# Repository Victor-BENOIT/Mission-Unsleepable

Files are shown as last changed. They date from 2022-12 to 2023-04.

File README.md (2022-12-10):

# Mission-Unsleepable

**Embedded Systems Project - November 2022**

**Collaborator:** Maxence Bigot

**Goal of the project:** 
For our Embedded Systems course, we had to come up with a project using the DEEP Purple Complete Board, a PCB card designed by the ESEO. Maxence and I decided to create an alarm clock that will wake you up everytime. However, smooth waking up is not guaranteed.

**Fonctioning:**
When the alarm rings, you have to push the button on the hatch to stop it. Nevertheless, when your hand will be detected by the sensor the hatch will flip and you will not be able to stop the alarm. If you take away your hand, the hatch will rotate back to its original position and reveal you the button. The only way to stop the alarm is to have a hand on top of the alarm clock, and to push the button underneath the lid through the hole in the back.

**Features:**
- Video alarm
- Custom ringtone and video
- Navigation through menus and options with a joystick

**Components:**
- LCD Screen 3 inches ILI9341
- Servo Motor MG996R
- Ultrasonic Sensor HCSR04
- Button
- Joystick
- Speaker TMQ60500
- Audio Amplificator PAM8403
- mp3 Player HW311
- Nucleo STM32
- BluePill
- Deep Purple Complete Board

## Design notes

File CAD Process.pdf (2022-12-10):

Victor BENOIT

# CAD Process

# Embedded Systems Project

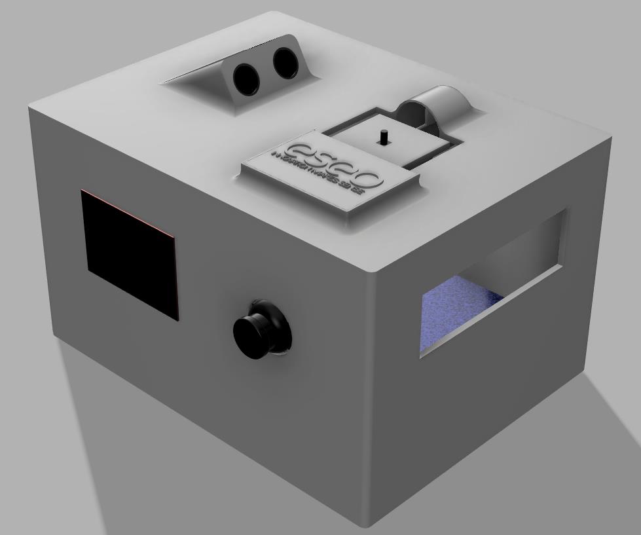
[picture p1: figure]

# MISSION UNSPLEEPABLE

# Steps of design development:

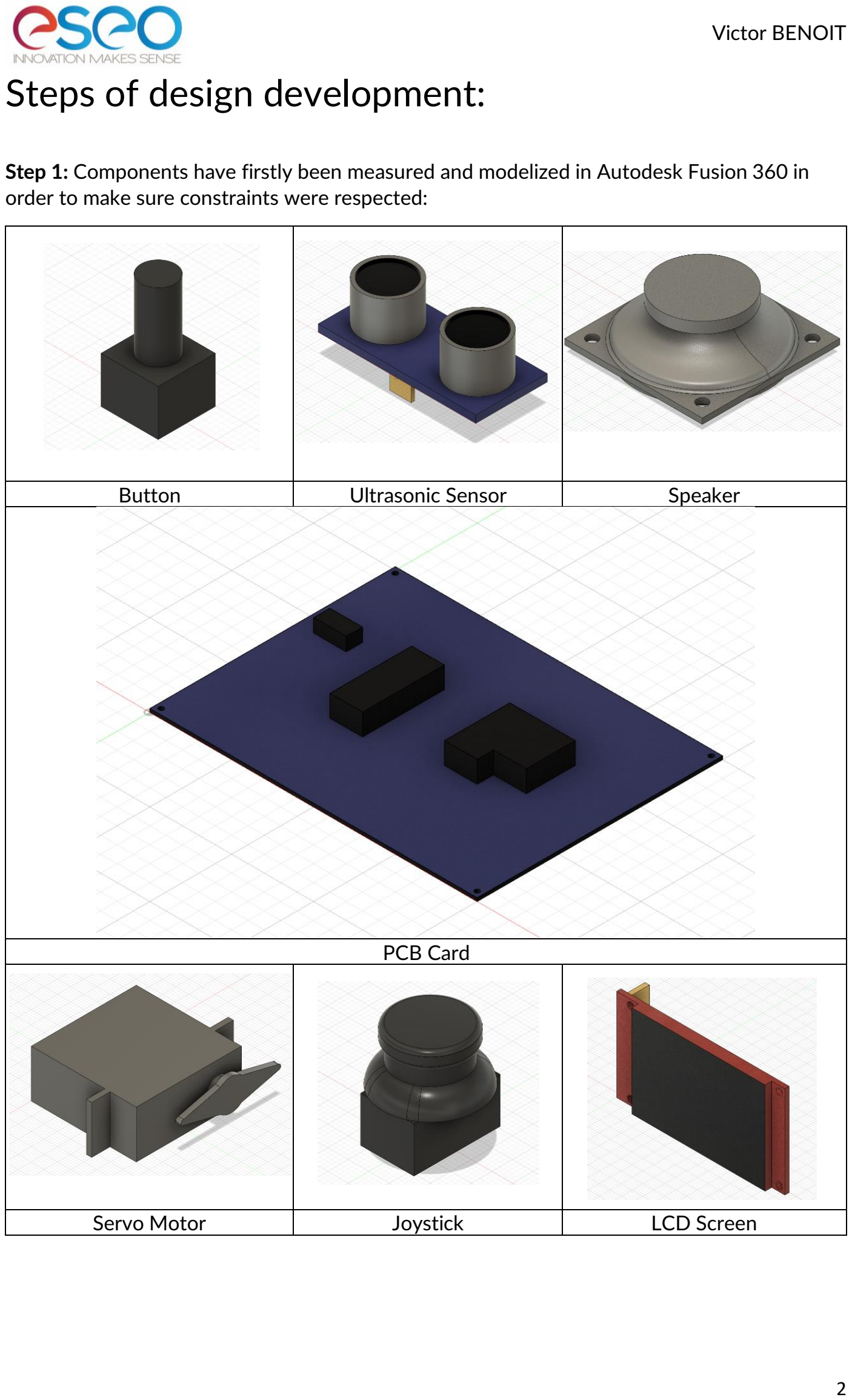
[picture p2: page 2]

Step 1: Components have firstly been measured and modelized in Autodesk Fusion 360 in order to make sure constraints were respected:
Button | Ultrasonic Sensor | Speaker

PCB Card

Servo Motor | Joystick | LCD Screen

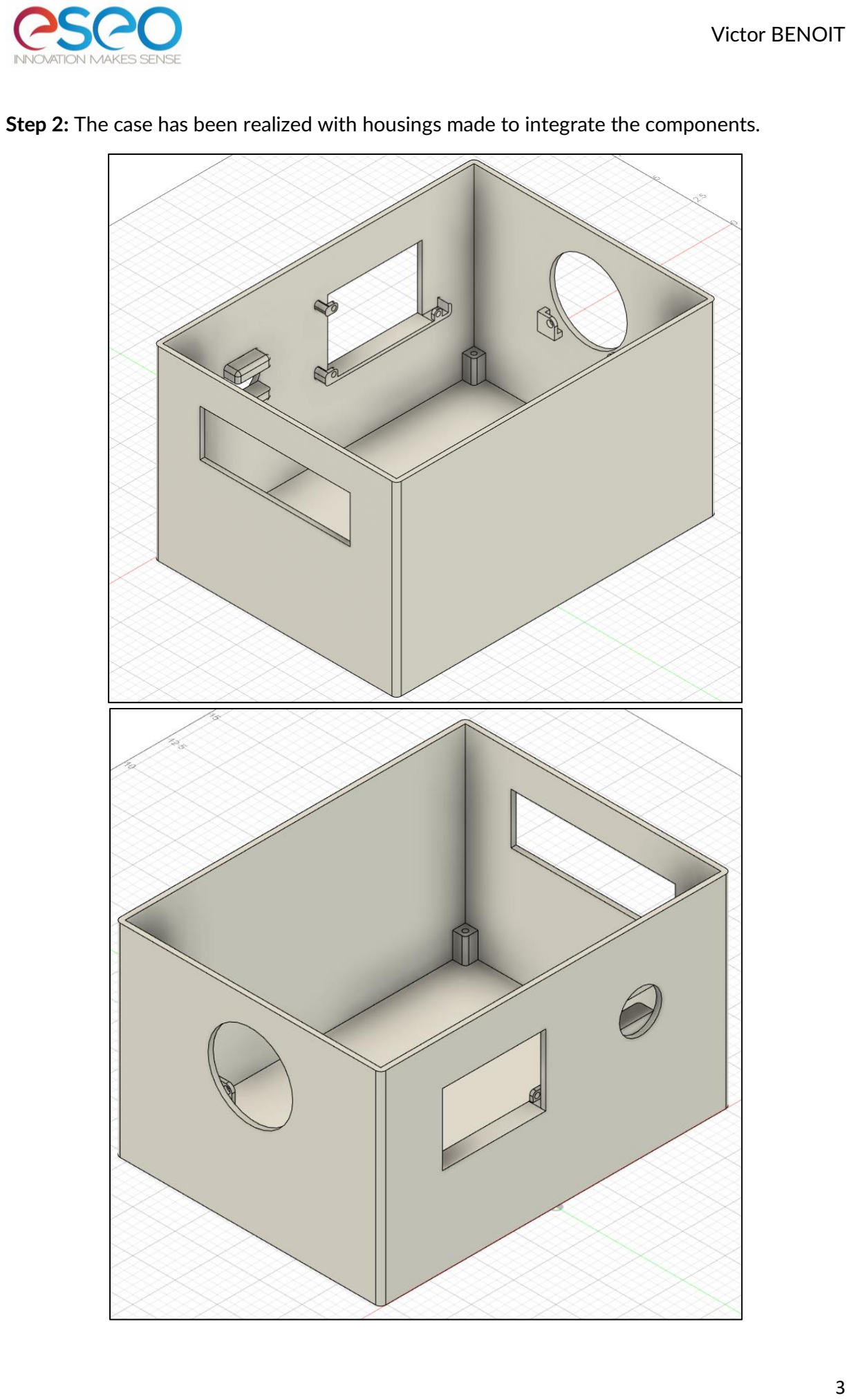
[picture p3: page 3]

Step 2: The case has been realized with housings made to integrate the components.

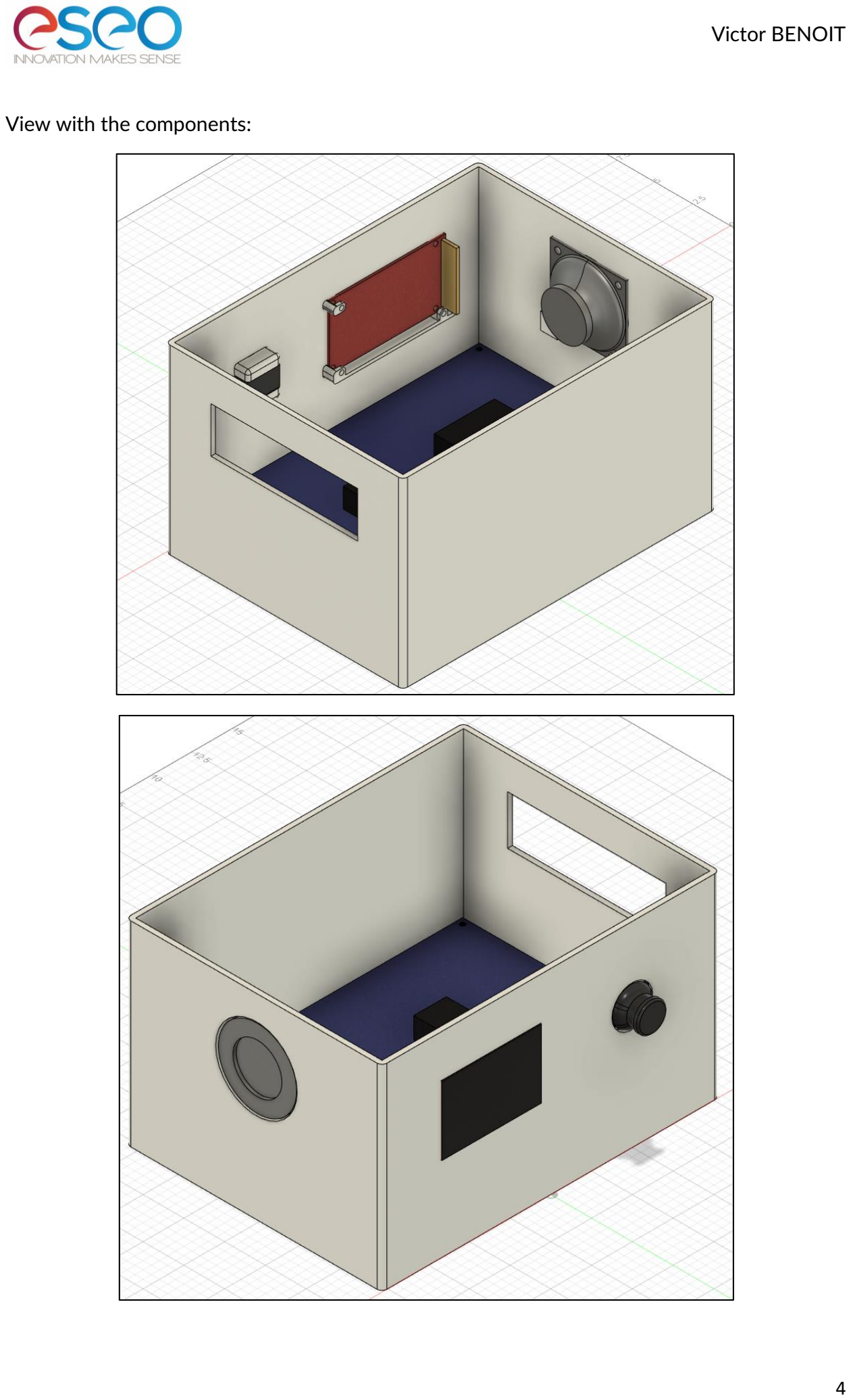
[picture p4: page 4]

View with the components:

Example of a fixation system:

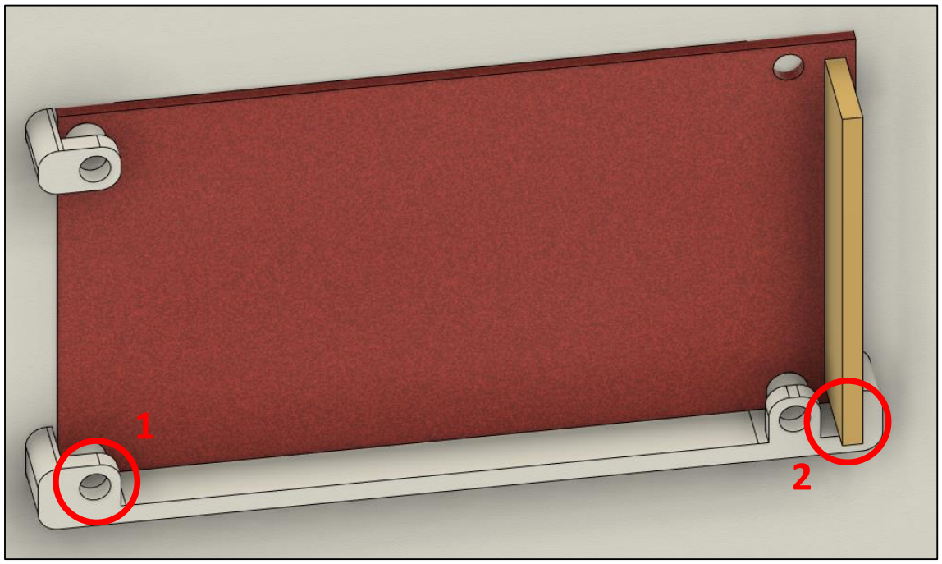
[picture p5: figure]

1) Space of 0.5mm made to slide the LCD Screen in from the top and then push it into the housing. The width of the screen is 0.3mm and the card 0.2mm. Once pushed in, bolts of 0.3mm can be placed to fix the component.
2) Space planned to have access to the pins of the LCD. Ledge designed to maintain the horizontal support of the card.

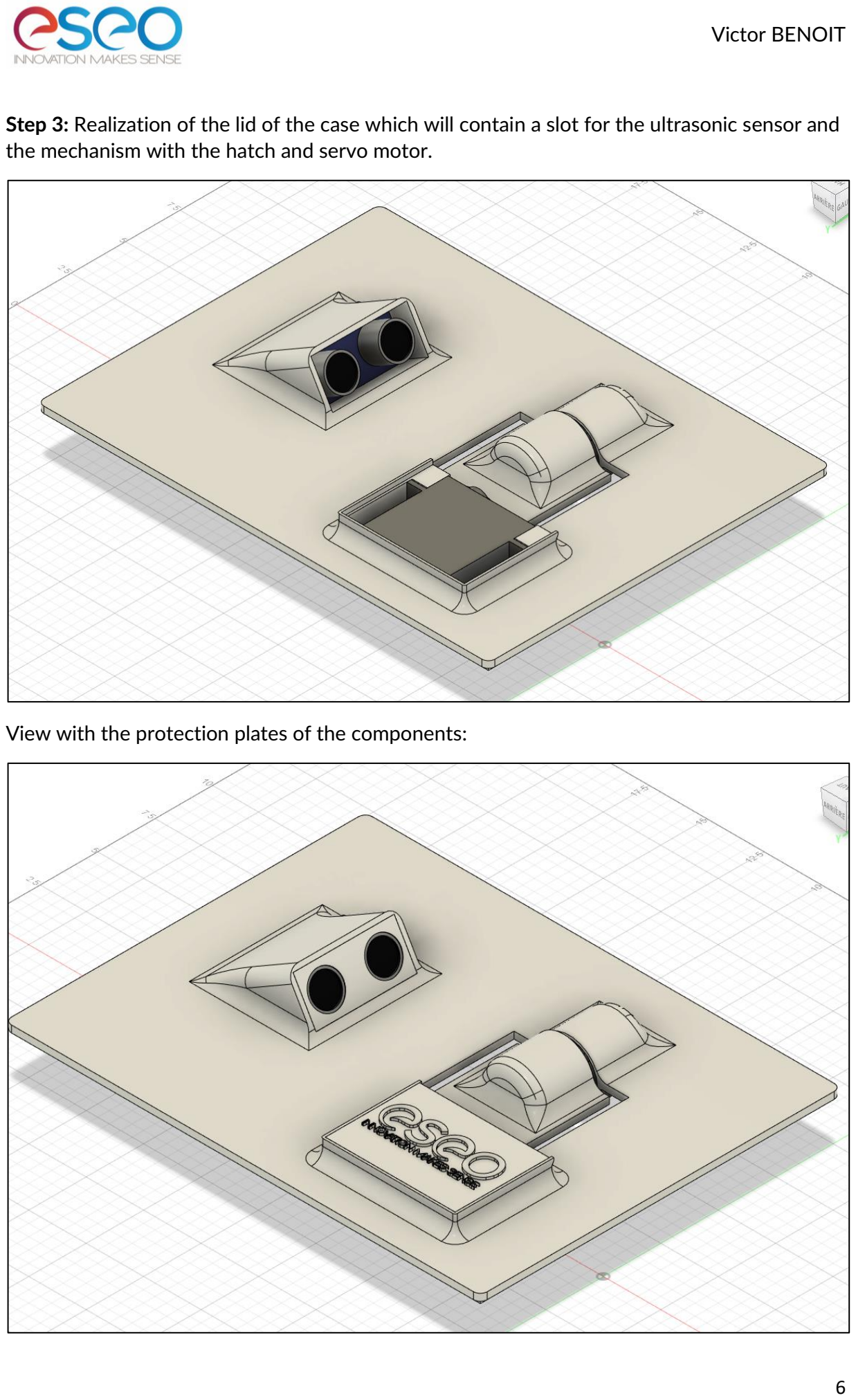
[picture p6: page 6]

Step 3: Realization of the lid of the case which will contain a slot for the ultrasonic sensor and the mechanism with the hatch and servo motor.

View with the protection plates of the components:

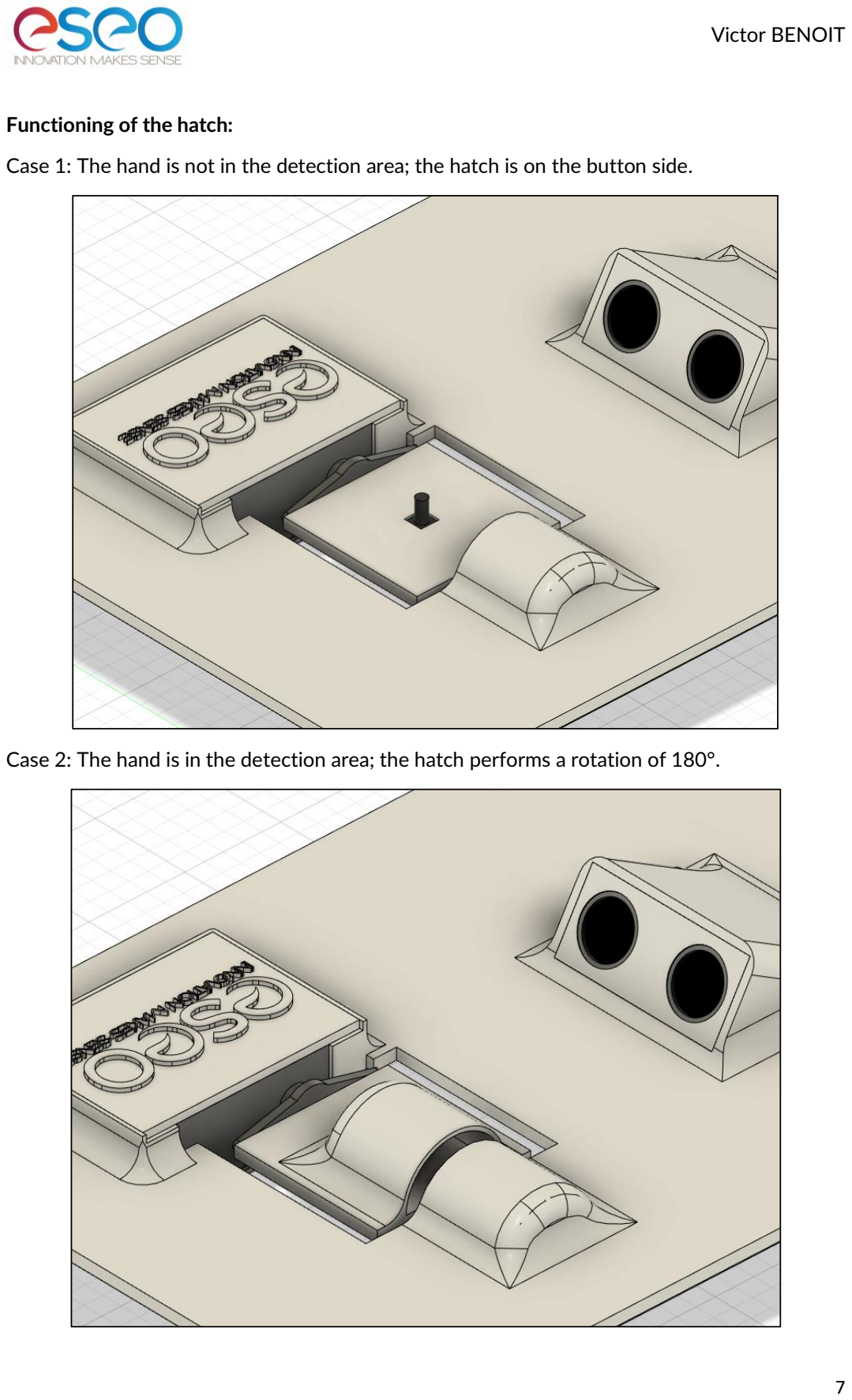
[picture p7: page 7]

Functioning of the hatch:

Case 1: The hand is not in the detection area; the hatch is on the button side.

Case 2: The hand is in the detection area; the hatch performs a rotation of 180°.

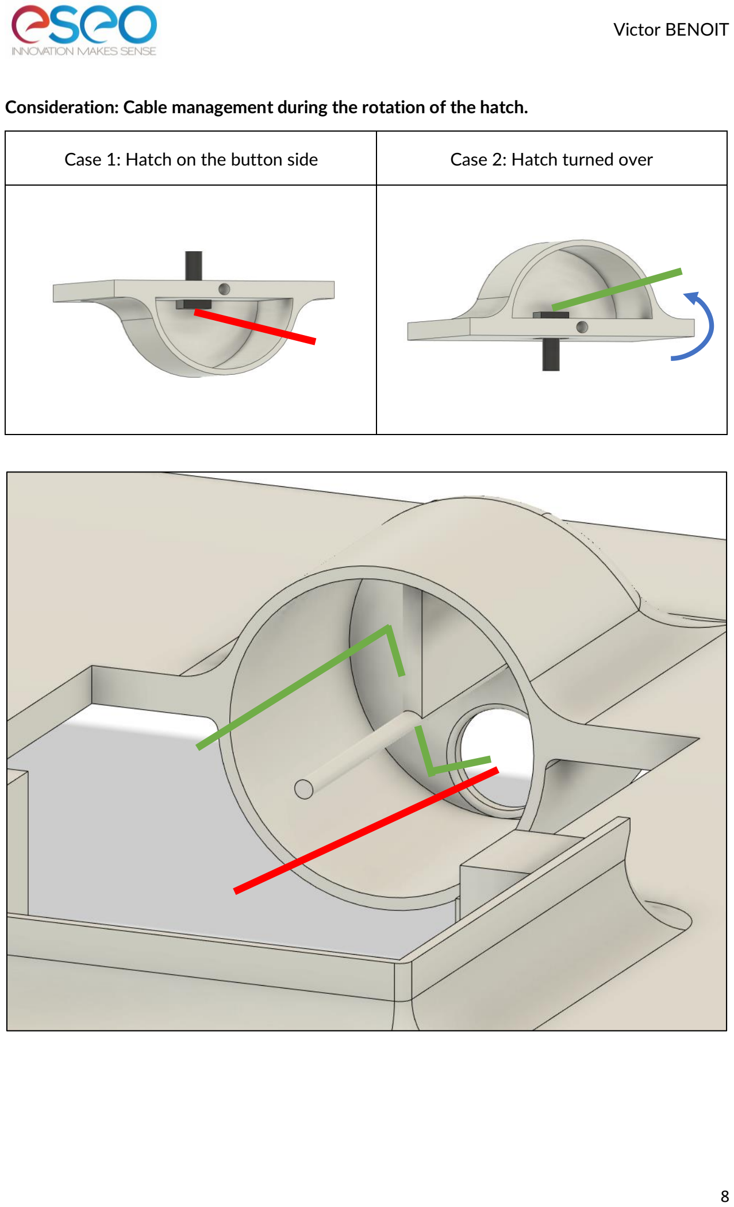
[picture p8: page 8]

Consideration: Cable management during the rotation of the hatch.

Case 1: Hatch on the button side | Case 2: Hatch turned over

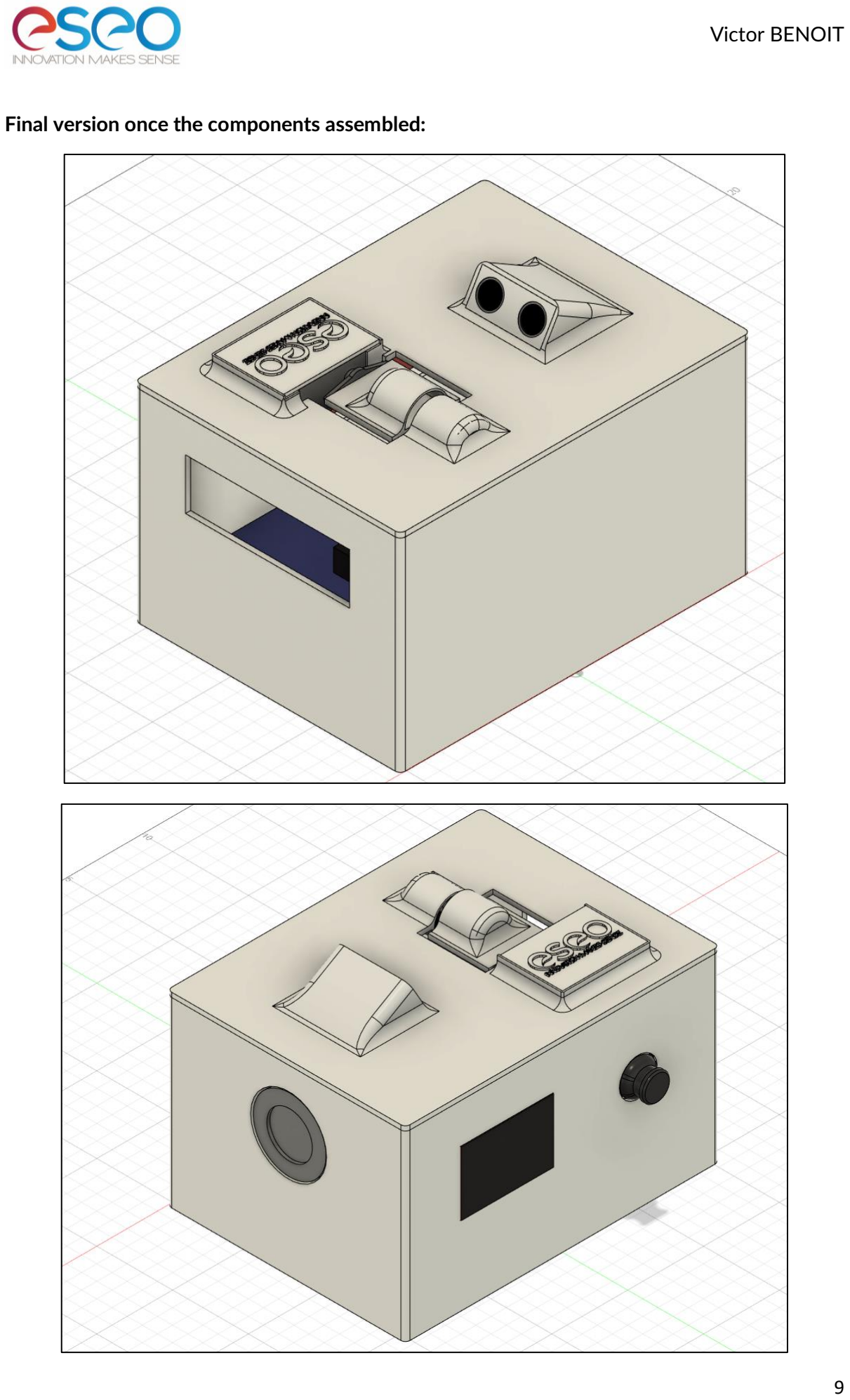
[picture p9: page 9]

Final version once the components assembled:

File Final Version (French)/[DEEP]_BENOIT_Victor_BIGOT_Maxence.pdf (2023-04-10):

Victor BENOIT
Maxence BIGOT
E3e Groupe A1

# Rapport Final

# Projet DEEP

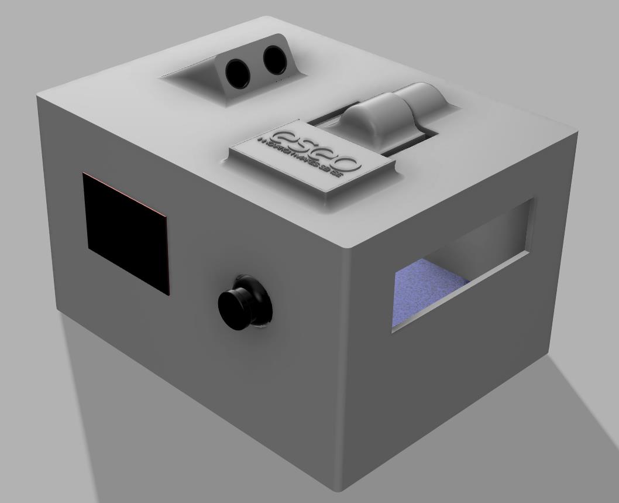
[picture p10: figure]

# MISSION UNSPLEEPABLE

# Introduction du Projet :

L’objectif de notre projet DEEP est de réaliser un réveil qui réveillera à coup sûr l’utilisateur. Pour se faire, nous allons utiliser les connaissances apprises lors des différentes missions réalisées auparavant, aussi bien Hardware que Software.

Ce rapport contient l’avancement qui a été fait sur la totalité des séances, le cahier des charges, les composants utilisés, les ports associés, et les compléments.

# Sommaire :

## 1. Compléments choisis

## 2. Cahier des charges

## 3. Manuel d’utilisation

## 4. Composants utilisés

## 5. Tableau d’affection des ports

## 6. Description d’un algorithme du programme

## 7. Structure du programme

## 8. Tests

## 9. Carnet de bord

## 10. Etat d’avancement et analyse du projet

## 11. Conclusion

## 12. Design CAO

## 13. Design PCB

## 14. Doxygen

# 1. Compléments choisis :

Complément (voir l’annexe correspondante à la fin du rapport) | pts
A- utilisation d'un analyseur logique pour déchiffrer des trames | 2 | ☐
B- design de PCB
avec bluepill | 3 | ☒
Composants CMS et microcontrôleur nu | 4 | ☐
C- design CAO d'un boîtier | 2 | ☒
D- documentation doxygen du code source | 1 | ☒
E- mesure de conso et d’énergie selon scénarios | 2 | ☐
F- enregistrement de paramètres en flash | 1 | ☐
G- gestion de version du code source / Git ou SVN | 1 | ☐
T- jeu de tests pour valider une fonctionnalité software ou hardware | 1 | ☐
Nombre de points ciblés au maximum : | 6 / 6

# 2. Cahier des charges :

Nous avons choisi de réaliser un réveil avec affichage LCD. Il y aura un menu parcourable grâce à un joystick dans lequel on pourra régler l’heure, l’alarme, et les différents modes.

L’utilisateur aura la possibilité de choisir le son de l’alarme. Pour éteindre l’alarme il y aura un bouton placé sur une plateforme à bascule qui pivotera grâce à un servomoteur. Sur la face supérieure sera placé un capteur à ultrason, qui détectera la présence de la main de l’utilisateur. A partir d’une certaine distance entre le capteur et la main, le servomoteur fera basculer la plateforme de 180° rendant l’appui sur le bouton impossible. Lorsque la main sera reculée, la plateforme reprendra sa position initiale. Pour vraiment arrêter l’alarme, l’utilisateur devra garder sa main au-dessus du capteur et appuyer sur le bouton avec sa 2e main en dessous.

Les contraintes sont principalement physiques : Il faut réaliser une structure de boitier à la fois solide et légère, de façon à avoir un réveil qui ne casse pas s’il tombe de la table de nuit (ou si il est jeté par l’utilisateur fou de rage), mais qui soit facile à déplacer. De plus le boitier doit posséder des logements permettant d’encastrer les composants et de les fixer pour qu’ils ne se déplacent pas à l’intérieur, tout en laissant la possibilité de les extraire s’ils doivent être changé. Pour finir, la conception mécanique doit prendre en compte la gestion des câbles lors de la rotation de la plateforme, sans gêner le mouvement et qu’il soit réalisable un grand nombre de fois.

# 3. Manuel d’utilisation :

Le produit est comparable à un réveil classique. Voici les différentes fonctionnalités : Affichage du jour, de la date, de la sonnerie, et de l’heure de l’alarme. Ces deux dernières sont aussi personnalisables grâce au menu d’options.

La valeur ajoutée de ce produit est de vous réveiller à coup sûr car pour éteindre l’alarme à votre réveil le matin il faudra appuyer sur un bouton fixé sur une trappe, trappe qui pivotera quand votre main approchera. Pour désactiver l’alarme, il faudra garder votre main au-dessus du réveil et appuyer sur le bouton en dessous avec votre 2e main.

# 4. Composants utilisés :

Nom/Référence du Composant | Utilisation/Fonctionnement
Ecran LCD 3 pouces ILI9341 | Ecran utilisé pour naviguer dans le menu principal. Option tactile non utilisée car le pilotage se fera avec le joystick. Option lecture de carte SD utilisée pour lire les vidéos. Résolution : 320x240. Alimentation en 3.3V.

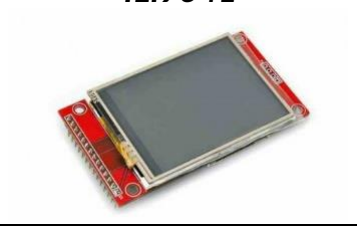
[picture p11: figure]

Servo Moteur MG996R | Moteur utilisé pour entrainer la plateforme dans une rotation de 180°. Le choix du duty du signal PWM permet de choisir sa rotation : 0.1 → 90° 0.2 → 180° Alimentation en 5V.

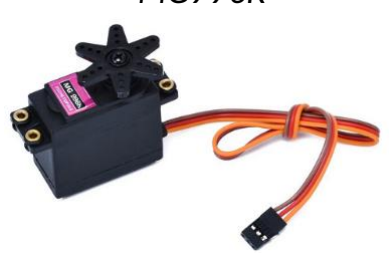
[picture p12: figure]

Capteur Ultrason HCSR04 | Capteur utilisé pour détecter la présence de la main à partir d’une certaine distance réglable avec le soft. Alimentation en 5V.
Bouton poussoir | Bouton placé sur la trappe permettant d’éteindre l’alarme quand elle sonne.
Joystick | Joystick placé à côté de l’écran permettant de naviguer dans le menu de paramétrages. (Remplacé par des boutons dans la version finale, voir partie 10)

Hautparleur TMQ60500 | Hautparleur permettant d’avoir une alarme musicale personnalisée.
Amplificateur Audio PAM8403 | Amplificateur permettant de régler le volume sonore de l’hautparleur.
Lecteur mp3 HW311 | Lecteur mp3 utilisé pour la lecture des musiques téléchargées sur la carte SD.

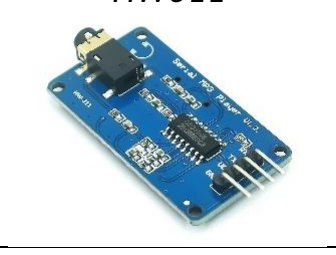
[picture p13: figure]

BluePill | Placée sur la DEEP Purple Complete Board. Permet la gestion des périphériques.
Nucleo STM32 | Permet à la BluePill d’utiliser la partie débugueur de la Nucleo STM32

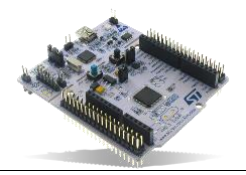
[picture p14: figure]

# 5. Tableau d’affectation des ports :

Composants Pins (Côté composant)

Pins (Côté
Bluepill)

Ecran LCD

VCC | 3,3V
GND | GND
CS | PB11
RESET | PB10
D/C | PB1
MOSI / T_DIN | PA7
SCK / T_CLK | PA5
LED | 3,3V
MISO / T_DOUT | PA6
T_IRQ | PA4
T_CS | PA0

Servo Moteur

VCC | 5V
GND | GND
PWM | PA8

Capteur
Ultrason
VCC | 5V
ECHO | PB5
TRIGGER | PB4
GND | GND

Lecteur MP3

VCC | 5V
TX | PB7
RX | PB6
GND | GND
Amplificateur | VCC | 5V
| GND | GND

Bouton
Poussoir
VCC | 3,3V
GND | GND
DATA Bouton Gauche | PA1
DATA Bouton Centre | PA2
DATA Bouton Droite | PA3

# 6. Description d’un algorithme

Pour la partie Software, nous avons commencé à programmer l’écran LCD. Pour ce faire, nous avons importé la librairie Ili9341. Dans le fichier config.h, nous avons défini l’utilisation de l’écran ainsi que la taille d’écriture. Après initialisation et rotation à l’horizontale (fonction ILI9341_Rotate), il nous reste juste à afficher des caractères ASCII au position x et y voulues avec la fonction ILI9341_Puts.

Puis, pour réaliser notre mission principale, l’affichage de l’heure et la date, nous avons besoin d’utiliser le capteur RTC. Pour cela, nous avons besoin de créer 2 structures de type RTC_TimeTypeDef et RTC_DateTypeDef de la librairie RTC. Pour chaque structure, nous définissons des attributs entiers non signés 8 bits (Hours, Minute, Seconds pour le temps et Date, Month, Year pour la date).

Grâce à l’horloge interne, le module est capable d’incrémenter le temps. Nous avons à utiliser les fonctions RTC_get_time(&currentTime) et RTC_get_date(&currentDate) pour récupérer nos informations avec les pointeurs. Cependant, nous devons transformer les attributs en chaine de caractères pour pouvoir les afficher sur l’écran. Pour cela, on initialise 2 variables, tableau de char, timeString et dateString. Il nous reste à utiliser la méthode sprintf comme ci-dessous.

Enfin, pour utiliser le réveil, nous avons besoin de jouer une musique. Pour cela, il nous faut configurer le lecteur MP3. Nous avons à préalable enregistrer une chanson dans la carte SD du lecteur. Le module MP3 communique en série avec la carte Bluepill. Pour transmettre des commandes, nous allons donc utiliser la communication UART. Pour cela, on initialise une liaison de 9600 Baud sur les pins RX et TX (PB6, PB7).

Les data à transmettre sont des listes de nombres hexadécimaux. Au minimum, nous avons 2 ordres à transmettre pour jouer une musique (l’accès à la carte SD et la lecture de la musique 1). On retrouve alors 2 tableaux de caractères hexadécimaux.

Il nous reste à envoyer les ordres sur le lecteur avec la fonction UART_puts.

D’un point de vue Software, le système complet sera représenté par une machine à états. Nous avons donc créer les différents états (voir schéma ci-dessous) dans une structure ENUM et une variable booléenne entrance pour l’entrée dans un état.

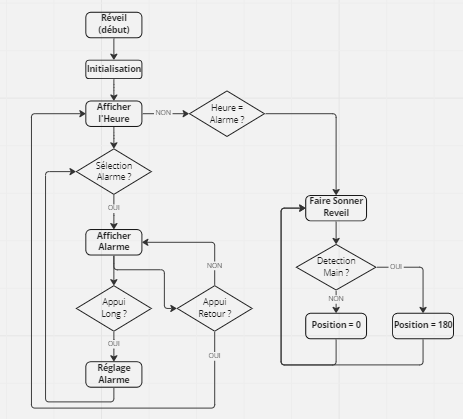
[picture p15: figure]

# 7. Structure du programme

Liste des fichiers :

FICHIER STATE.C

Nom de la fonction | Paramètres | Retour | Description
State_machine | | | Gère la machine à état du système

FICHIER VARIABLE.C

Nom de la fonction | Paramètres | Retour | Description
getAlarm | | Alarme | Obtenir les données de l’alarme
setAlarmHours | Entier 8bits | | Modifier la variable Hours
getListMusics | | Tableau de Musique | Obtenir les données de ListMusics

FICHIER BUTTON.C

Nom de la fonction | Paramètres | Retour | Description
button_left_press_event | | Booléen ret | Gestion de l’appui simple du bouton
button_center_press_event | | Booléen ret | Gestion de l’appui simple du bouton
button_right_press_event | | Booléen ret | Gestion de l’appui simple du bouton

FICHIER SETHOUR.C

Nom de la fonction | Paramètres | Retour | Description
screen_hours | Alarme | | Affichage sur l’écran des élements uniques
| | | | l’heure
changeAlarmHourVariable | | | | Gérer la modification de l’ heure
setHourString | Alarme | Affichage de

Les fichiers SetMinute, SetMusic et AlarmeRing suivent le même principe.

FICHIER RTC.C

Nom de la fonction | Paramètres | Retour | Description
initModuleRTC | Year, Month, Date, Hour, Minute, Second | | Initialiser le module RTC

FICHIER HCSR04.C

Nom de la fonction | Paramètres | Retour | Description
hcsr04_state_machine | | | Machine à état du capteur à ultrason

FICHIER MP3PLAYER.C

Nom de la fonction | Paramètres | Retour | Description
initPlayer | | | Initialiser le lecteur mp3
playMusic | Entier | | Jouer une musique
stopMusic | | | Stopper la musique

FICHIER SERVO.C

Nom de la fonction | Paramètres | Retour | Description
SERVO_init | | | Initialiser le servomoteur
SERVO_set_position | Entier | | Fixer le servomoteur à une position précise
getCurrentPosition | | Entier | Récupérer la positon courante

# 8. Tests :

Nom du Test | Description | Résultat
Test de l’alimentation | Mesure au voltmètre des entrées. On attend 5V. | Validé
Test d’envoi UART | Mesure à l’oscilloscope. On doit observer un changement de tension lorsqu’une commande est envoyée. | Validé
Test Lecteur mp3 | Mesure à l’oscilloscope. On doit observer un changement de tension lorsqu’une musique est envoyée. | Validé
Test Servomoteur | Mesure à l’oscilloscope. On doit observer le signal PWM avec le bon Duty. | Validé
Test Ecran | Vérification visuelle de l’écriture sur l’écran | Validé
Test Bouton poussoir | Mesure à l’oscilloscope. On doit observer un changement de tension lorsque l’on appuie sur le bouton. | Validé

# 9. Carnet de Bord :

Date | Tâches, réalisateurs, difficultés rencontrées. | A faire la prochaine fois
08/11/22 | Victor Benoit & Maxence Bigot : Réflexion sur le projet | Choix des composants
10/11/22 | Victor Benoit & Maxence Bigot : Choix des composants | Définir les broches utilisés
15/11/22 | Victor Benoit & Maxence Bigot : Définition des broches utilisés, Réalisation de la fonction Alimentation | Soudure des composants de la carte
17/11/22 | Victor Benoit & Maxence Bigot : Soudure des composants | Développement soft, Soudure des composants restants, Conception Boitier
22/11/22 | Victor Benoit : Soudure des composants restants, Conception du boitier Maxence Bigot : Développement soft – Ecran LCD – capteur RTC | Développement Soft Lecteur de carte SD, Conception Boitier
24/11/22 | Victor Benoit : Conception Boitier Maxence Bigot : Développement soft – Ecran LCD – Lecteur carte SD | Développement Soft du Servomoteur, Soudure et Câblage
29/11/22 | Victor Benoit : Développement soft – Servomoteur – HCSR04 Maxence Bigot : Soudure + Câblage Hautparleur, Lecteur mp3 | Rédaction du rapport intermédiaire, Développement Soft UART
01/12/22 | Victor Benoit : Rédaction du rapport intermédiaire Maxence Bigot : Développement Soft UART & Hautparleur | Développement Soft Hautparleur & Conception maquette démo
06/12/22 | Victor Benoit : Découverte d’Altium et routage de la PCB Maxence Bigot : Développement Soft UART & Hautparleur | Continuer la conception de la PCB, Créer les variables Globales Musiques et Alarme
13/12/22 | Victor Benoit : Tracé des nets de la PCB Maxence Bigot : Création des variables globales Musiques et Alarme | Continuer la conception de la PCB, Développement des différents affichages de l’écran

15/12/22 | Victor Benoit : Tracé des nets, DRC, Estimation du coût de production Maxence Bigot : Développement des différents affichages de l’écran | Rédiger le rapport du complément PCB, Gestion des boutons poussoirs
03/01/23 | Victor Benoit : Rédaction du rapport de complément PCB, Rédaction du rapport final Maxence Bigot : Gestion des boutons poussoirs | Continuer la rédaction du rapport final, Vérification générale du projet
19/01/23 | Victor Benoit : Rédaction du rapport final Maxence Bigot : Vérification générale du projet

# 10. Etat d’avancement et analyse du projet réalisé :

La partie Hardware est terminée, tous les composants utilisés ont été soudés sur la DEEP Purple Complete Board. Nous avons aussi préparé beaucoup de broches femelles nous permettant de placer et enlever les composants comme bon nous semble afin de mieux manipuler la plaque PCB. La partie CAO est terminée, le boitier est fonctionnel et prêt pour une potentielle impression. Le design de la PCB est terminé mais une version avec les composants qui assurent la fonction du son pourrait être envisagée.

La partie Software est pratiquement terminée. Les principaux objectifs ont été réalisé comme l’affichage de l’heure et de la date, l’affichage de l’alarme et son réglage. Nous
pouvons également ajouter des musiques dans la carte SD et manuellement dans le code pour qu’elle puisse être utiliser comme sonnerie. Le servomoteur est fonctionnel. Le seul problème est le capteur à ultrason HCSR04 qui ne fonctionne pas.

Avec plus de temps et une meilleure approche dans le projet, nous pourrions ajouter d’autres fonctionnalité comme l’annulation de l’alarme ou le réglage du capteur à ultrasons. Nous avons décidé d’utiliser des boutons à la place du joystick car c’est plus simple à utiliser.

Malgré tout, il nous reste des composants à paramétrer. Nous avons perdu du temps à cause des erreurs mémoires qui provoquent l’erreur « asm volatile », les boutons poussoirs qui étaient mal soudés au début. Avant d’utiliser les getters et setters pour l’alarme, on n’arrivait pas à modifier ses attributs.

Le document du lecteur MP3 indiquait que l’on pouvait mettre une valeur hexadécimale à 0x01 pour obtenir des informations retour de l’actionneur. Cependant, cela envoyait une mauvaise commande et nous n’arrivions pas à jouer une musique avec cette valeur.

# 11. Conclusion :

Nous sommes fiers de la réalisation de ce projet réveil. Même si la partie mécanique n’est pas encore fonctionnelle, le système de base du réveil marche très bien. Nous avons aussi ajouté certaines options avec succès, le choix de musique personnalisée notamment. Nous avons perdu du temps sur l’implémentation des capteurs et le débogage. Pour finaliser totalement le projet, il ne nous manquerait plus qu’à assurer le fonctionnement simultané de tous les périphériques.

# 12. Design CAO :

Les composants ont tout d’abord été mesurés et modélisés dans Fusion 360 pour s’assurer que les contraintes étaient respectées :

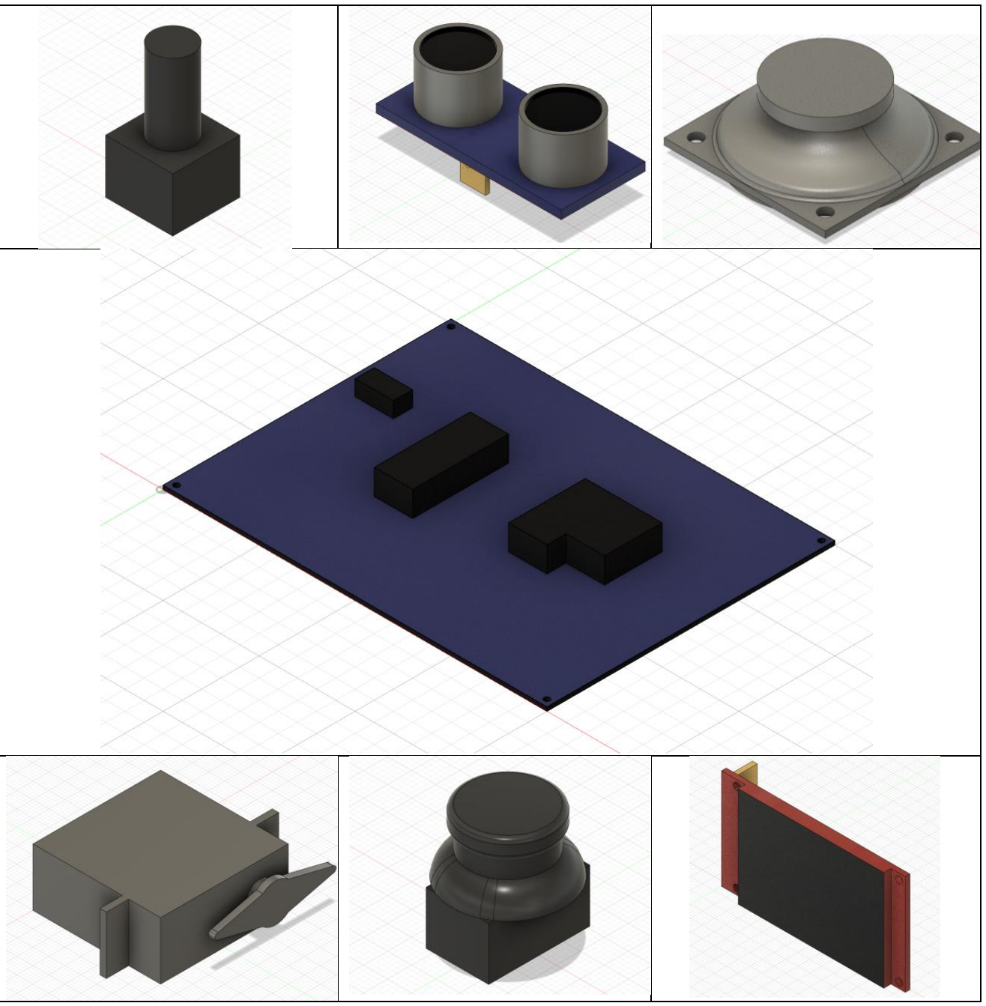
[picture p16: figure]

La 2e étape était de réaliser le boitier avec les encastrements pour les composants.

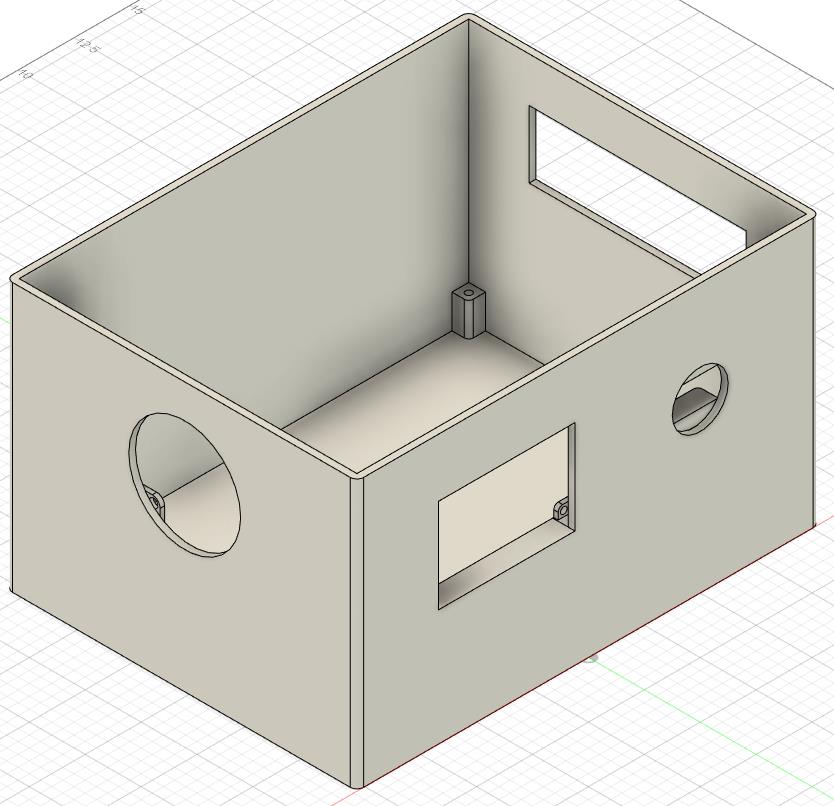
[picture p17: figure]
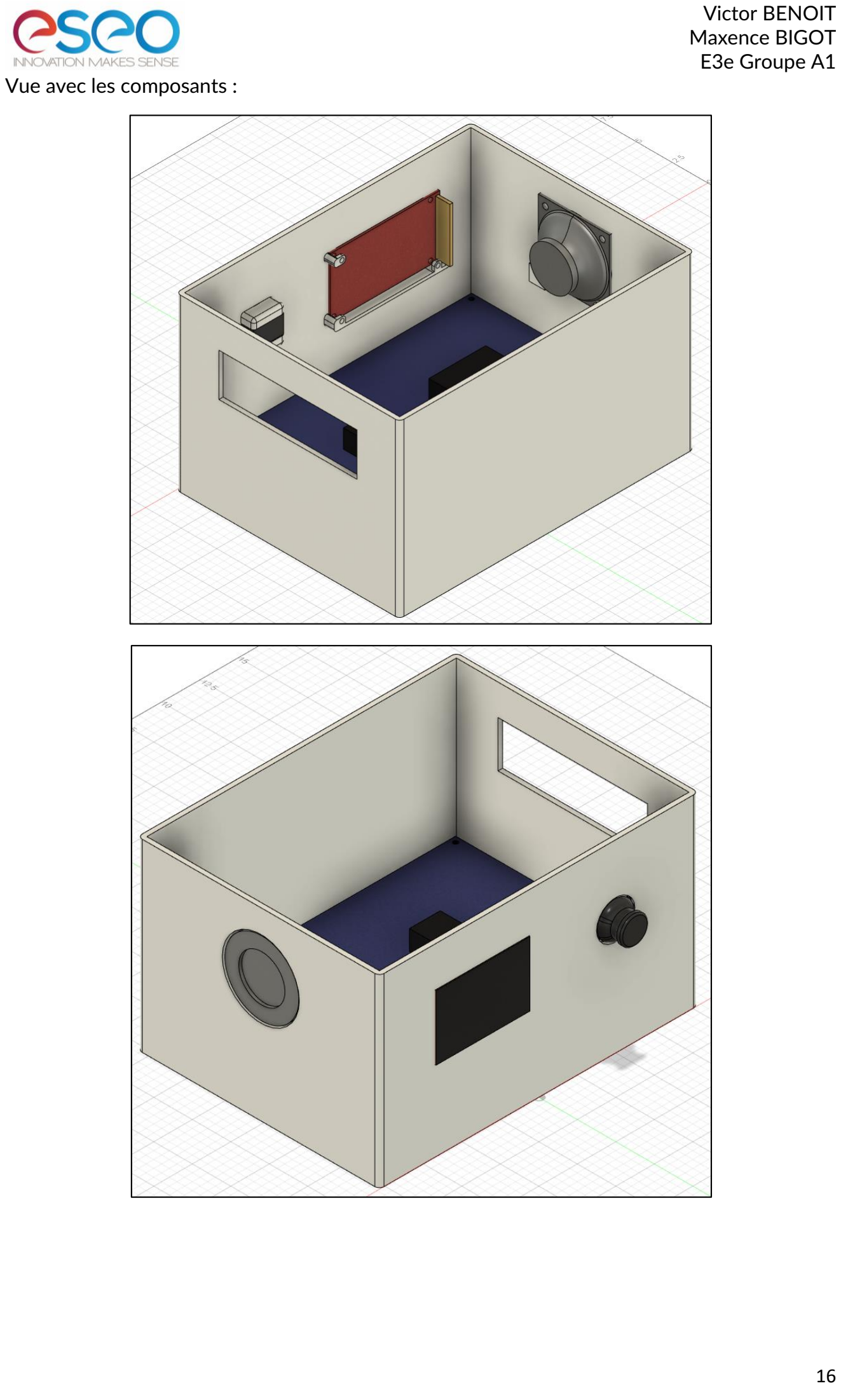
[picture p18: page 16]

Vue avec les composants :

Exemple de système de fixation :

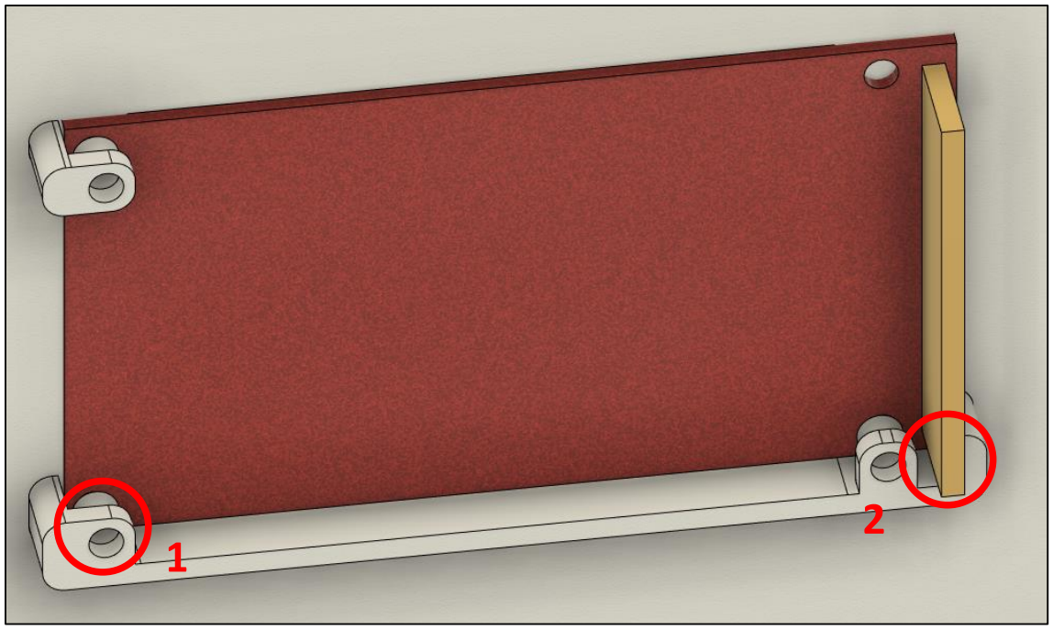
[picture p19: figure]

1) Espace de 0.5mm (comblé ensuite par un boulon de 0.3mm et l’épaisseur de la carte de 0.2mm). Permet de glisser le composant de haut en bas, puis de le pousser dans la paroi (l’épaisseur de la partie LCD et de la paroi sont de 0.3mm)
2) Espace prévu pour laisser l’accès aux broches de l’écran LCD. Rebord permettant le maintien horizontal de la carte.

La 3e étape était de réaliser le couvercle de la boite, qui va comprendre un emplacement pour maintenir le capteur ultrasons et la partie mécanique avec la trappe et servomoteur.

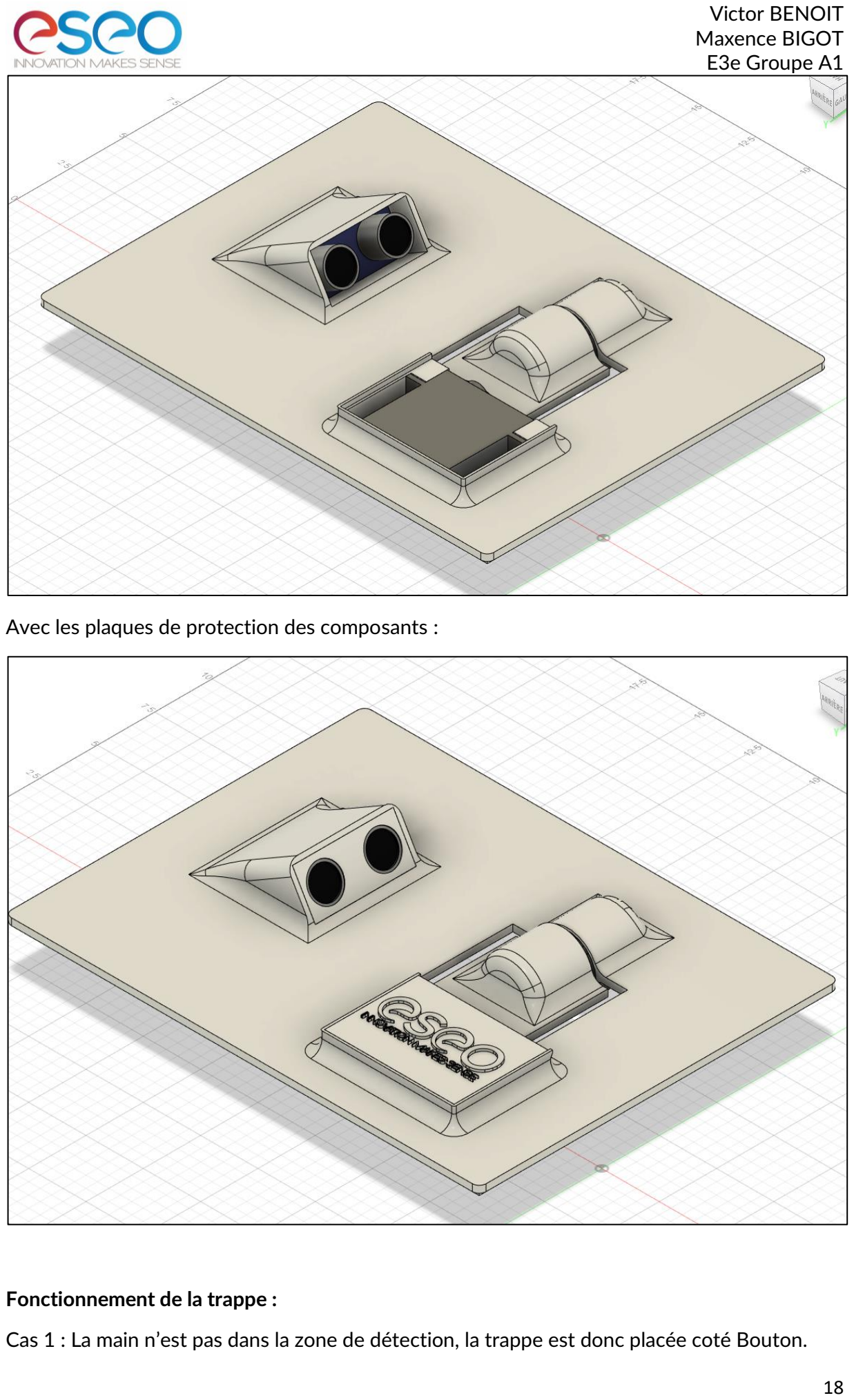
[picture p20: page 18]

Avec les plaques de protection des composants :

Fonctionnement de la trappe :

Cas 1 : La main n’est pas dans la zone de détection, la trappe est donc placée coté Bouton.

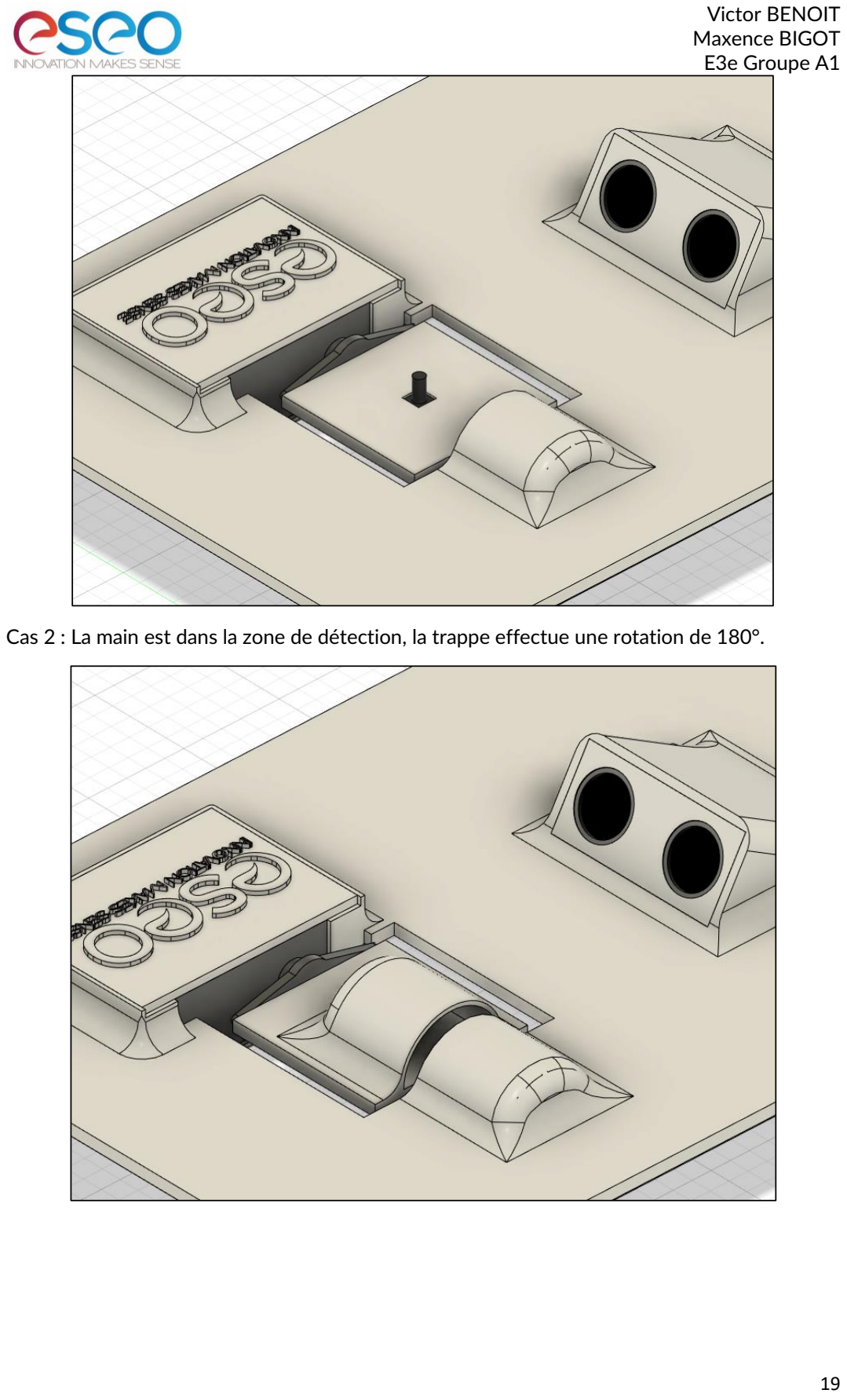
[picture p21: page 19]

Cas 2 : La main est dans la zone de détection, la trappe effectue une rotation de 180°.

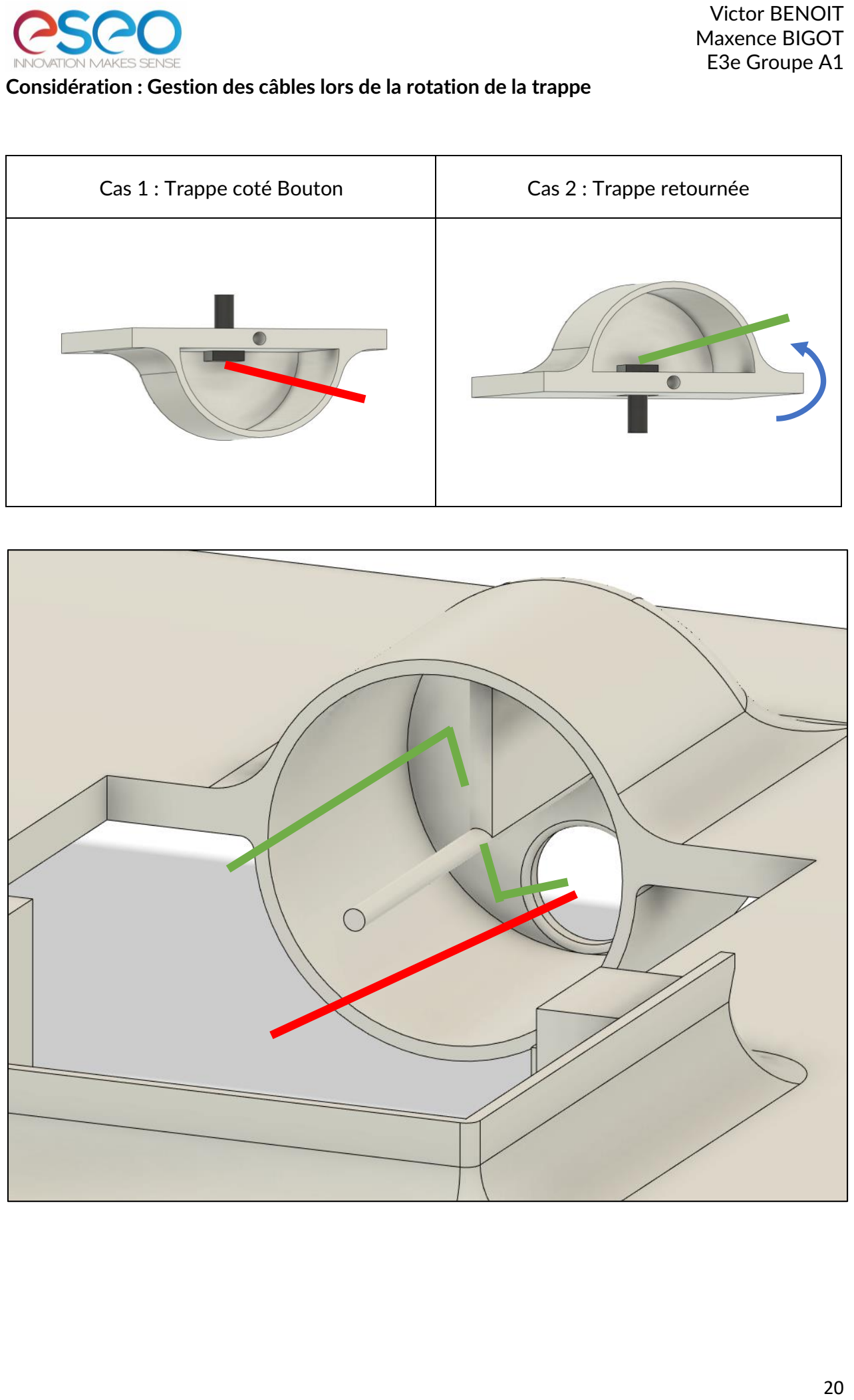
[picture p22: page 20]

Considération : Gestion des câbles lors de la rotation de la trappe

Cas 1 : Trappe coté Bouton | Cas 2 : Trappe retournée

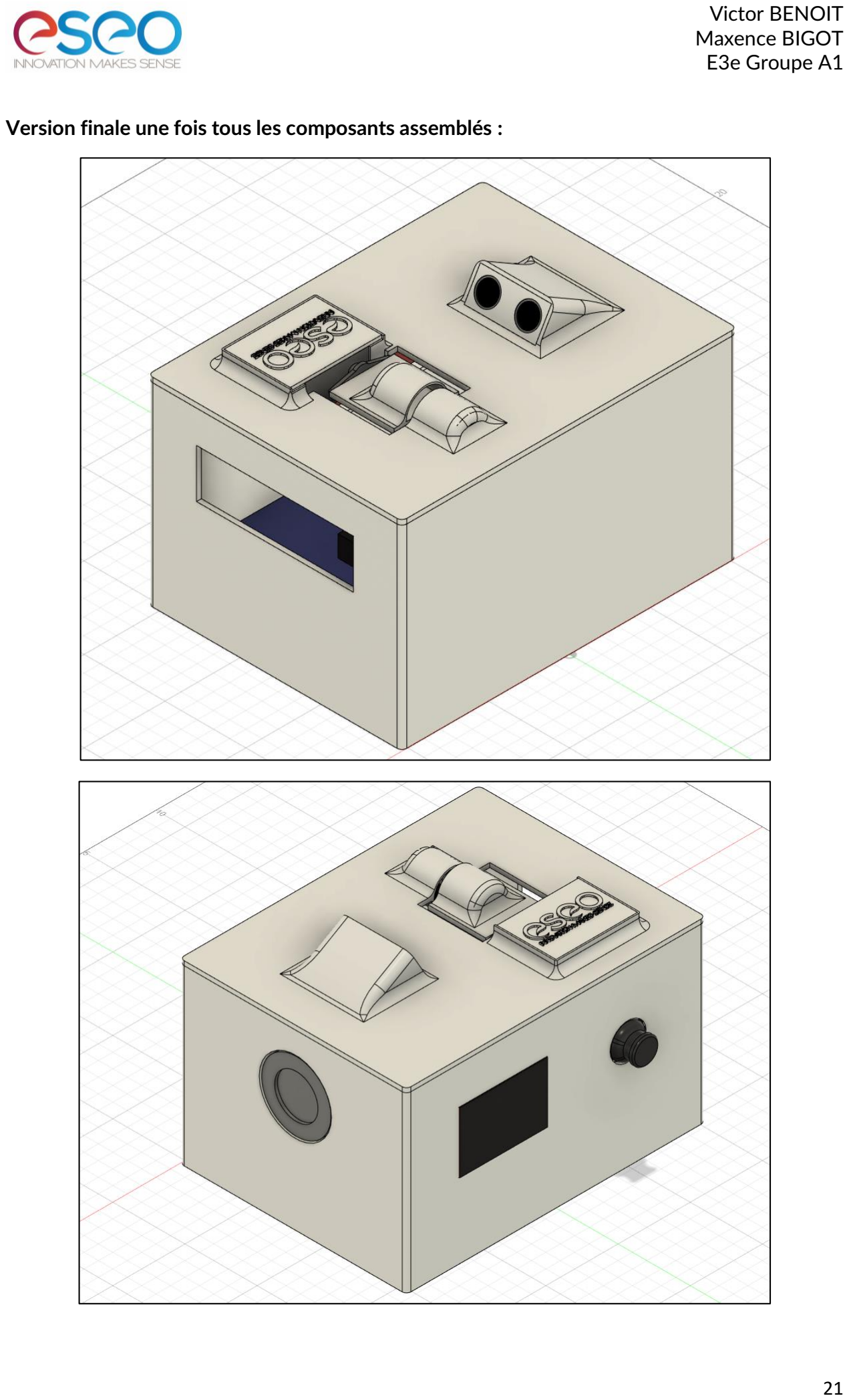
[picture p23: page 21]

Version finale une fois tous les composants assemblés :

# 13. Design PCB :

Nous penserons à joindre à l’archive zip livrable : notre fichier SchDoc, notre fichier PcbDoc ainsi que le PDF généré par Altium contenant schéma, vue des couches de routage et vue 3D. | ☒
Les connecteurs sont accessibles | ☒
Un plan de masse est présent sur chaque couche de cuivre | ☒
Les GND sont correctement tous reliés par des pistes (même si le plan de masse les regroupe ensuite). | ☒
Le DRC (Design Rules Check) passe sans aucune erreur | ☒
Présence d'un connecteur UART (Rx + Tx + GND), parce que c'est toujours utile | ☐
Si le microcontrôleur est placé en CMS : présence d’un connecteur de programmation (SWDIO + SWDCLK + GND) | ☐
Pas d’arrivée en TOP non soudables sur des composants traversants | ☒
Noms des étudiants et site (Angers/Vélizy/Dijon) visibles sur le TOP. | ☒
Carte aux dimensions raisonnables (pas trop d’espace libre !) | ☒
Pistes >= 12 mils ; et au moins 25 mils lorsque c’est possible | ☒
Clearance >= 20mils lorsque c’est possible. (Ponctuellement >= 10mils) Clearance des plans de masse réglée à 40 mils. | ☒
Un schéma correct | 75/100
Qualité du placement (un bon placement garanti un bon routage) | 80 /100
Qualité du routage | 60 /100

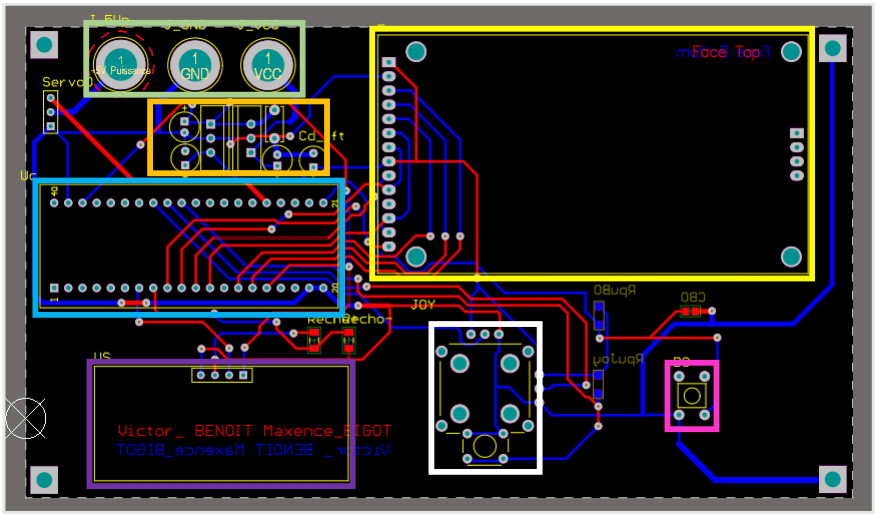
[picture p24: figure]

### Rôles des composants :

En vert, les bornes d’alimentation et de masse : Elles sont placées à l’extrémité de la carte pour faciliter l’emploi. Reliées à l’alimentation, elles permettent d’alimenter la carte.

En orange, la fonction alimentation : Permet d’alimenter les différents composants en 5V et 3,3V.

En bleu, la Bluepill : Elle permet la gestion des périphériques.

En violet, le capteur ultrason : Il communique par liaison UART et permet de détecter la distance à laquelle un objet est détecté, dans notre cas la main.

En jaune, l’écran LCD : Par défaut, il affiche l’heure. Si l’utilisateur veut changer des paramètres, il affiche le menu d’options.

En blanc, le joystick : Il permet de naviguer dans le menu d’options. (Remplacé par deux boutons dans la version réelle car utilisation plus pratique.)

En rose, un bouton : Il permet de désactiver l’alarme quand celle-ci sonne.

### Vue 2D du routage :


### Vue 3D de la carte :


### Difficultés rencontrées :

- Routage des nets au niveau de la Bluepill : Il y avait beaucoup de chevauchements donc j’ai dû utiliser beaucoup de via.
- Prise en main du logiciel : Compliquée au début, mais une fois pris en main, l’utilisation est agréable.
- Certains composants introuvables : Je n’ai pas trouvé le lecteur mp3, l’amplificateur, et l’hautparleur donc je me suis résolu à faire une version sans.

### Estimations des couts de production :

On a donc un prix total de 73.27€ (sans compter les frais de port).

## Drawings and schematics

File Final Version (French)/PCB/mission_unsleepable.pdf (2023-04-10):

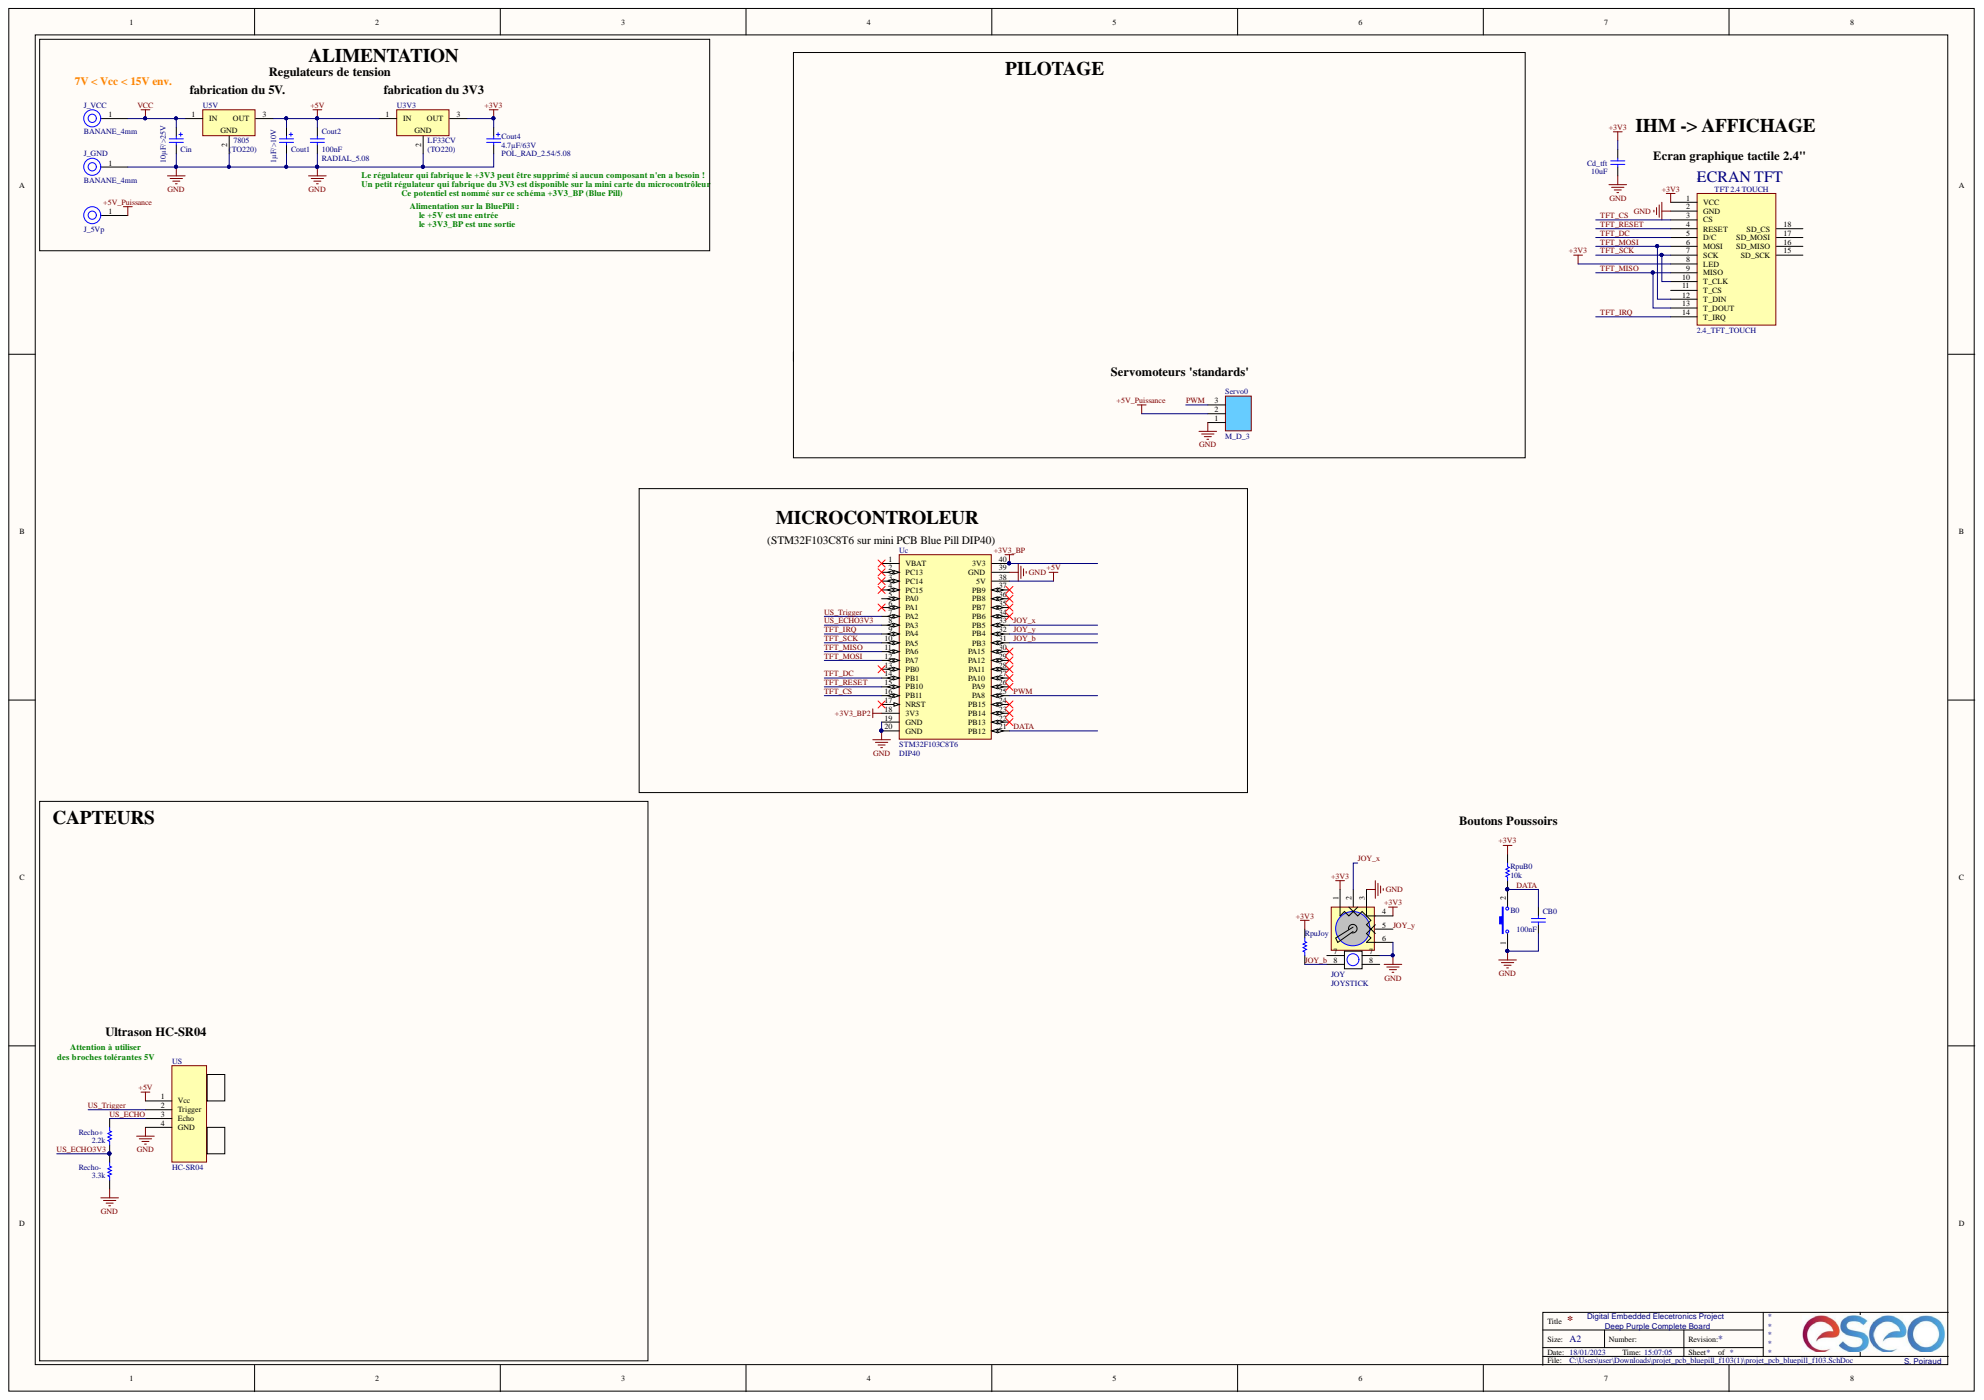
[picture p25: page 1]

Regulateurs de tension 7V < Vcc < 15V env.

Le régulateur qui fabrique le +3V3 peut être supprimé si aucun composant n'en a besoin !
Un petit régulateur qui fabrique du 3V3 est disponible sur la mini carte du microcontrôleur Ce potentiel est nommé sur ce schéma +3V3_BP (Blue Pill)

Alimentation sur la BluePill :
le +5V est une entrée
le +3V3_BP est une sortie

(STM32F103C8T6 sur mini PCB Blue Pill DIP40)

* Digital Embedded Elecetronics Project Title Deep Purple Complete Board | * * * * *

Size: A2 | Number: | Revision: *

Date: 18/01/2023 Time: 15:07:05 | | Sheet * of *

C:\Users\user\Downloads\projet_pcb_bluepill_f103(1)\projet_pcb_bluepill_f103.SchDoc

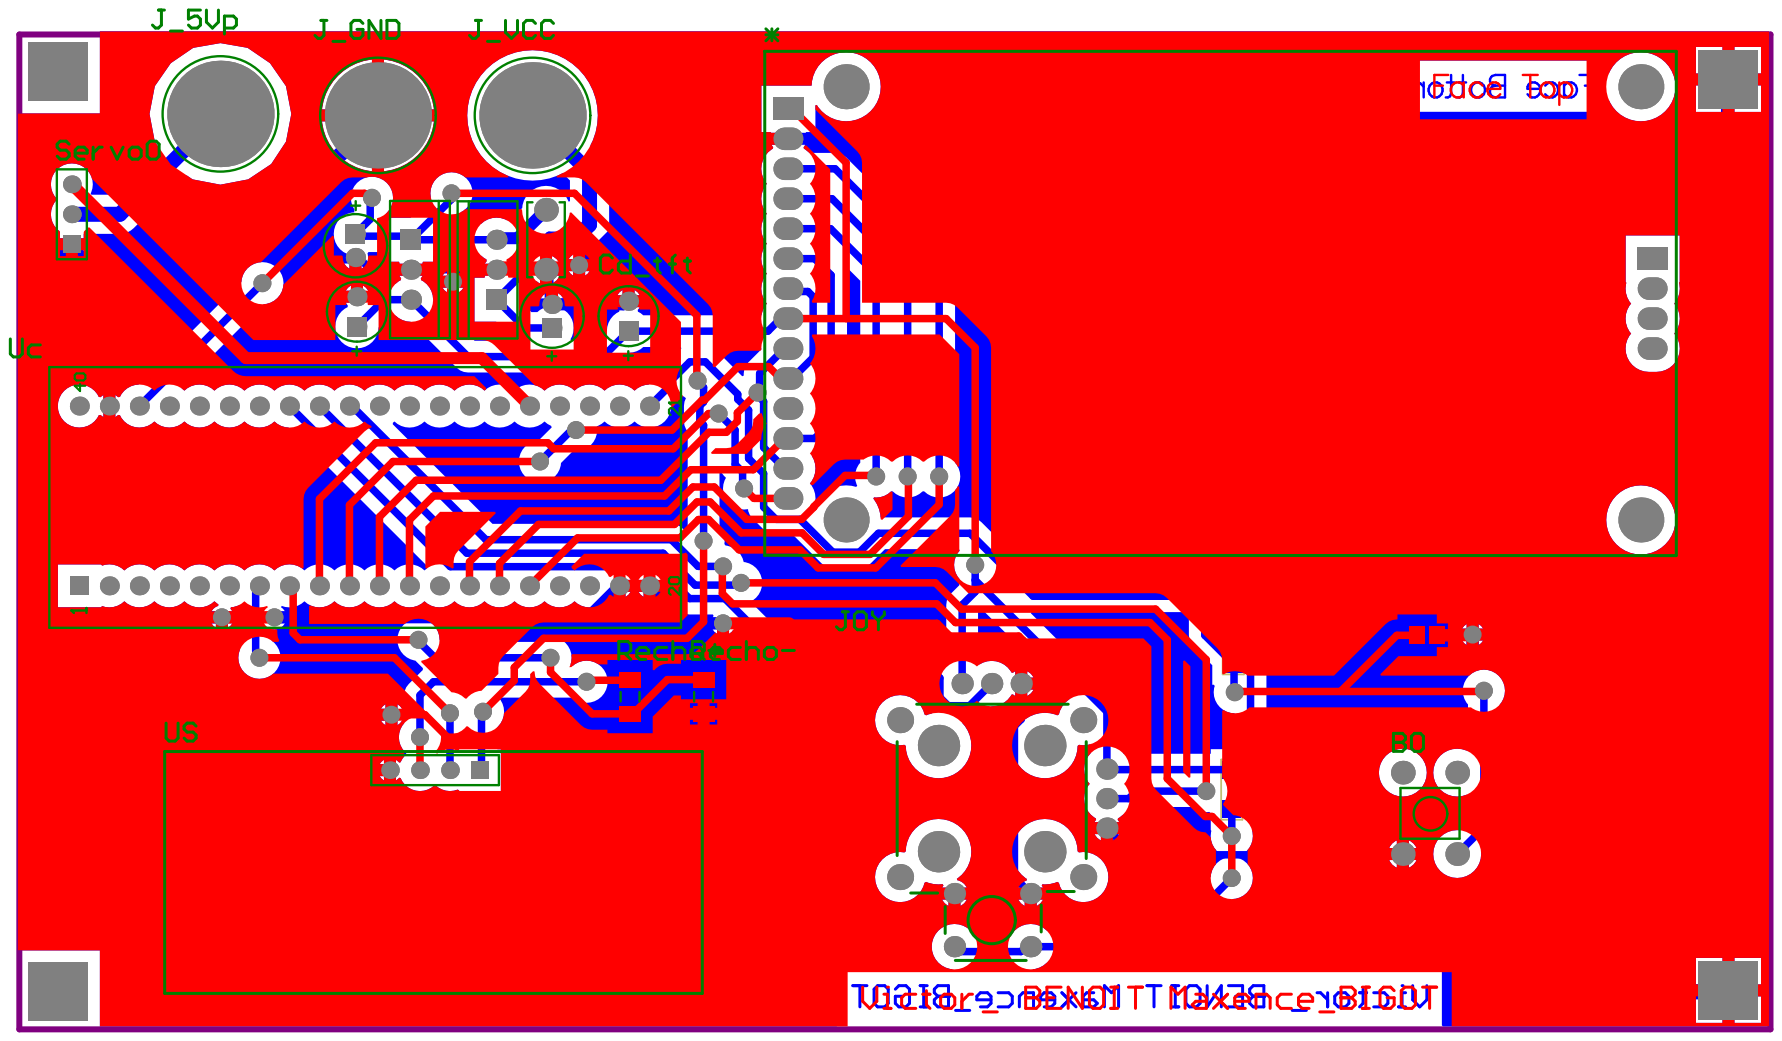
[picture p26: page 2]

# Board Stack Report

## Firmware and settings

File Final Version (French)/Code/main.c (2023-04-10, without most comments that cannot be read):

/**
  ******************************************************************************
  * @file    main.c
  * @author  Nirgal
  * @date    03-July-2019
  * @brief   Default main function.
  ******************************************************************************
*/
#include "stm32f1xx_hal.h"
#include "stm32f1_uart.h"
#include "stm32f1_sys.h"
#include "stm32f1_gpio.h"
#include "macro_types.h"
#include "systick.h"

#include "states.h"

static volatile uint32_t t = 0;
void process_ms(void)
{
    if(t)
        t--;
}

int main(void){
	//Initialisation de la couche logicielle HAL (Hardware Abstraction Layer)

	HAL_Init();




	//UART_init(UART2_ID,115200);
	UART_init(UART1_ID, 9600); // Lecteur MP3



	//SYS_set_std_usart(UART2_ID, UART2_ID, UART2_ID);



	Systick_add_callback_function(&process_ms);

	while(1){	//boucle de tache de fond
		state_machine();
	}
}

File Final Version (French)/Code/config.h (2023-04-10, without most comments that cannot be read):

/*
 * config.h
 *
 *  Created on: 31 mars 2016
 *      Author: Nirgal
 */

#ifndef CONFIG_H_
#define CONFIG_H_
#include "stm32f1xx_hal.h"


#define NUCLEO	0
#define BLUEPILL 1

#define MY_BLUEPILL_IS_COUNTERFEIT	BLUEPILL

#define TRACE	0


//_______________________________________________________

//Ces macros permettent d'utiliser dans le code des noms explicites (LED_GREEN, ...)
#if NUCLEO
	#define LED_GREEN_GPIO		GPIOA
	#define LED_GREEN_PIN		GPIO_PIN_5
	#define BLUE_BUTTON_GPIO	GPIOC
	#define BLUE_BUTTON_PIN 	GPIO_PIN_13
	#if BLUEPILL
		#error "Vous ne pouvez pas d�finir � la fois NUCLEO et BLUEPILL !"
	#endif
#endif
#if BLUEPILL
	#define LED_GREEN_GPIO		GPIOC
	#define LED_GREEN_PIN		GPIO_PIN_13

	#define LEFT_BUTTON_GPIO 	GPIOA			//BOUTON POUSSOIR GAUCHE
	#define LEFT_BUTTON_PIN		GPIO_PIN_1

	#define CENTER_BUTTON_GPIO 	GPIOA			//BOUTON POUSSOIR CENTRAL
	#define CENTER_BUTTON_PIN	GPIO_PIN_2

	#define RIGHT_BUTTON_GPIO 	GPIOA			//BOUTON POUSSOIR DROIT
	#define RIGHT_BUTTON_PIN	GPIO_PIN_3


#endif


#define UART1_ON_PB6_PB7
//#define UART1_ON_PA9_PA10


#define UART2_ON_PA2_PA3
//#define UART2_ON_PD5_PD6


#define UART3_ON_PB10_PB11
//#define UART3_ON_PD8_PD9


//_______________________________________________________


//Ci dessous, les defines permettant d'activer les modules de la librairie.



#define USE_BSP_EXTIT			1 //Utilisation du module de gestion des it externe : stm32f1_extit.c/h

#define USE_INTERNAL_FLASH_AS_EEPROM	0

#define USE_BSP_TIMER			1 //Utilisation de stm32f1_timer.c/h


#define USE_ADC					1



	#define USE_AN0			1	//Broche correspondante : PA0
	#define USE_AN1			1	//Broche correspondante : PA1
	#define USE_AN2			1
	#define USE_AN3			0
	#define USE_AN4			0	//Broche correspondante : PA4
	#define USE_AN5			0	//Broche correspondante : PA5
	#define USE_AN6			1	//Broche correspondante : PA6
	#define USE_AN7			1	//Broche correspondante : PA7
	#define USE_AN8			1	//Broche correspondante : PB0
	#define USE_AN9			0	//Broche correspondante : PB1
	#define USE_AN10		0
	#define USE_AN11		0
	#define USE_AN12		0
	#define USE_AN13		0
	#define USE_AN14		0
	#define USE_AN15		0
	#define USE_AN16		0
	#define USE_AN17		1	//Vref


#define USE_SCREEN_TFT_ILI9341		1	//Ecran TFT 2.4
	#if USE_SCREEN_TFT_ILI9341
		#define USE_XPT2046			0	//Tactile

		#define USE_FONT11x18		1
		#define USE_FONT7x10		0
		#define USE_FONT16x26		1

		#if BLUEPILL
			#define ILI9341_CS_PORT       GPIOB
			#define ILI9341_CS_PIN        GPIO_PIN_11

			#define ILI9341_WRX_PORT      GPIOB
			#define ILI9341_WRX_PIN       GPIO_PIN_1

			#define ILI9341_RST_PORT      GPIOB
			#define ILI9341_RST_PIN       GPIO_PIN_10
		#endif /* BLUEPILL */
	#endif


#define USE_SCREEN_LCD2X16			0	//Ecran LCD 2x16

#define USE_TFT_PCD8544				0	//Ecran TFT Nokia

//Carte capteur IKS01A1 :
#define USE_SENSOR_HTS221		0
#define USE_SENSOR_LPS25HB		0
#define USE_SENSOR_LSM6DS0		0
#define USE_SENSOR_LIS3MDL		0//Magnetometre

//Autres capteurs :
#define USE_SENSOR_LSM6DS3		0
#define USE_SENSOR_LPS22HB		0
#define USE_MLX90614			0
#define USE_MPU6050				0
#define USE_DHT11				0

#define USE_MATRIX_KEYBOARD		0
#define USE_MATRIX_LED			0
#define USE_CAPACITIVE_KEYBOARD	0
#define USE_MATRIX_LED_32_32	0
#define USE_FINGERPRINT			0

#define USE_MCP23S17			0 //Port expander I/O en SPI
#define USE_MCP23017			0 //Port expander I/O en I2C
#define USE_APDS9960			0
#define USE_BH1750FVI			0
#define USE_BMP180				0	//Capteur de pression
#define USE_MOTOR_DC			0
#define USE_STEPPER_MOTOR		0
#define USE_RTC					1
#define USE_PWM					1
#define USE_ESP8266				0//Module Wifi
#define USE_NFC03A1				0
#define USE_EPAPER				0
#define	USE_GPS					0
#define USE_HCSR04				1
#define USE_HX711				0
#define USE_DAC_MCP4921			0
#define USE_IR_EMITTER			0
#define USE_IR_RECEIVER			0
#define USE_IR_RECEIVER_NEC		0
#define USE_DS18B20				0
#define USE_MIDI				0
#define	USE_VL53L0				0
#if USE_VL53L0
	#define VL53L0X_I2C				I2C1
	#define VL53_NB					1

	#define VL_0					GPIOA, GPIO_PIN_0
	//#define VL_1					GPIOD, GPIO_PIN_3
	//#define VL_2					GPIOE, GPIO_PIN_10
#endif

#if USE_EPAPER
	#define RST_Pin 			GPIO_PIN_1
	#define RST_GPIO_Port 		GPIOA
	#define DC_Pin 				GPIO_PIN_1
	#define DC_GPIO_Port 		GPIOC
	#define BUSY_Pin 			GPIO_PIN_0
	#define BUSY_GPIO_Port 		GPIOB
	#define SPI_CS_Pin 			GPIO_PIN_4
	#define SPI_CS_GPIO_Port 	GPIOA
	#define EPAPER_SPI			SPI1
#endif

#define USE_SD_CARD				0

#define USE_DIALOG				0


#if USE_MLX90614 || USE_MPU6050	|| USE_APDS9960	 || USE_BH1750FVI || USE_BMP180 || USE_MCP23017 || USE_VL53L0
	#define USE_I2C				1
#else
	#ifndef USE_I2C
		#define USE_I2C		0
	#endif
#endif
#define I2C_TIMEOUT				5	//ms



#if USE_SCREEN_TFT_ILI9341	|| USE_SD_CARD
	#define USE_SPI				1
	#define SPI1_ON_PA5_PA6_PA7		1
	#define SPI1_ON_PB3_PB4_PB5		0
#endif

#if USE_IR_EMITTER || USE_MOTOR_DC
	#undef USE_PWM
	#define USE_PWM		1
#endif
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

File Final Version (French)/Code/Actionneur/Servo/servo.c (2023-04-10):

/**
 * @file servo.c
 * @brief Fichier pour utiliser le servomoteur
 *
 * @date 29/11/2022
 * @author Victor Benoit
 */

#include "Actionneur/Servo/servo.h"

static uint16_t current_position;


/**
 * @fn int getCurrentPosition(void)
 *  @date 29/11/2022
 *  @author Victor Benoit
 *  @return Position courante du servomoteur
 */
int getCurrentPosition(){
	return current_position;
}


/**
 * @fn void SERVO_init(void)
 * @brief Intialisation du servomoteur
 * @date 29/11/2022
 * @author Victor Benoit
 */
void SERVO_init(){
	TIMER_run_us(TIMER1_ID, 10*1000, FALSE);
	TIMER_enable_PWM(TIMER1_ID, TIM_CHANNEL_1, 150, FALSE, FALSE);
}


/**
 * @fn void SERVO_set_position(uint16_t position)
 * @brief Réglage du servomoteur à une postion donnée
 *
 * @date 29/11/2022
 * @author Victor Benoit
 * @param position Position (entier non signé 16 bits)
 */

void SERVO_set_position(uint16_t position){
	current_position = position;
	if(position > 100){
		position = 100;
	}

	position += 100;
	TIMER_set_duty(TIMER1_ID, TIM_CHANNEL_1, position);
}

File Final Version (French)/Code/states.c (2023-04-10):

/**
 * @file state.c
 * @brief Fichier qui gère la machine à  etats du reveil
 *
 *  @date 17/11/2022
 *  @author Maxence Bigot
 *  @bug Capteur ultrason HCSR04 ne fonctionne pas
 */

#include <Screens/SetHour/screen_hour.h>
#include "states.h"
#include "tft_ili9341/stm32f1_ili9341.h"
#include "stm32f1_rtc.h"
#include "stm32f1_uart.h"
#include "stm32f1_timer.h"
#include "stm32f1xx_hal.h"

#include "Variables/variables.h"
#include "Actionneur/Buttons/buttons.h"
#include "Actionneur/MP3Player/mp3_player.h"
#include "Actionneur/Servo/servo.h"
#include "Actionneur/RTC/rtc.h"
#include "Actionneur/HCSR04/hcsr04.h"

#include "Screens/Home/screen_home.h"
#include "Screens/SetHour/screen_hour.h"
#include "Screens/SetMinutes/screen_minute.h"
#include "Screens/SetMusic/screen_music.h"
#include "Screens/AlarmRing/screen_ring.h"


//Récupération de l'heure et de la date
RTC_DateTypeDef currentDate;
RTC_TimeTypeDef currentTime;


/**
 * @fn void state_machine(void)
 * @brief Gerer la machine à  états du reveil
 *
 * @date 17/11/2022
 * @author Maxence Bigot
 */
void state_machine(void){

	/**
	 * @enum state_e
	 * @brief Création des différents états du système
	 *
	 * @date 17/11/2022
	 * @author Maxence Bigot
	 */
	typedef enum{
		INIT = 0,
		HOME,
		SETHOUR,
		SETMINUTE,
		SETMUSIC,
		ALARMRING,
		SERVOMOTOR
	}state_e;

	static state_e state = INIT;
	static state_e previous_state = INIT;
	bool_e entrance;

	entrance = (state!=previous_state)?TRUE:FALSE;
	previous_state = state;


	switch(state){
		case INIT:
			// INITIALISATION DE L'ECRAN
			ILI9341_Init();
			ILI9341_Rotate(ILI9341_Orientation_Landscape_2);

			// INITIALISATION DES MODULES
			RTC_init(TRUE); //RTC
			initModuleRTC(23, 1, 20, 8, 32, 0);

			state = HOME;
			break;

		case HOME:
			if(entrance){
				screen_home(getAlarm()); //Affichage unique sur l'ecran
			}

			//Ecriture et Affichage en String de l'heure et date
			RTC_get_time(&currentTime);
			RTC_get_date(&currentDate);

			char timeString[5];
			char dateString[10];
			sprintf(timeString, "%d:%d", currentTime.Hours, currentTime.Minutes);
			sprintf(dateString, "%d/%d/%d", currentDate.Date, currentDate.Month, currentDate.Year + 2000);

			ILI9341_Puts(120, 55, timeString, &Font_11x18, ILI9341_COLOR_WHITE, ILI9341_COLOR_BLUE);
			ILI9341_Puts(21, 115, dateString, &Font_11x18, ILI9341_COLOR_WHITE, ILI9341_COLOR_BLUE);

			//Passage a l'etat suivant
			if(button_center_press_event()){
				state = SETHOUR;
			}

			if(getAlarm().Set){
				if(getAlarm().Hours == currentTime.Hours){
					if(getAlarm().Minutes == currentTime.Minutes){
						state = ALARMRING;
					}
				}
			}

			ILI9341_Delay(1000);
			break;


		case SETHOUR:
			if(entrance){
				screen_hours(getAlarm()); //Affichage unique sur l'ecran
				setHourString(getAlarm());
			}

			//Changer la valeur des minutes
			changeAlarmHourVariable(0);


			//Passage a  l'etat suivant
			if(button_center_press_event()){
				state = SETMINUTE;
			}

			break;


		case SETMINUTE:
			if(entrance){
				screen_minutes(getAlarm()); //Affichage unique sur l'ecran
				setMinuteString(getAlarm());
			}

			//Changer la valeur des minutes
			changeAlarmMinuteVariable();


			//Passage Ã  l'Ã©tat suivant
			if(button_center_press_event()){
				state = SETMUSIC;
			}

			break;

		case SETMUSIC:
			if(entrance){
				screen_musics(getAlarm()); //Affichage unique sur l'ecran
				setMusicString(getAlarm().Musique.Number, getAlarm()); //Affichage du titre sur l'ecran
			}

			changeMusicVariable();

			//Passage Ã  l'etat suivant
			if(button_center_press_event()){
				setAlarmSet(1);
				state = HOME;
			}

			break;


		case ALARMRING:
			if(entrance){
				screen_alarm_ring(getAlarm()); //Affichage de l'ecran

				initPlayer(); //Initialisation de la carte SD du lecteur MP3
				playMusic(getAlarm().Musique.Number); //Play la musique de l'alarme

				SERVO_init(); //Servomoteur
				SERVO_set_position(0); //Servo moteur a  0%
				HAL_Delay(2000);
			}

			/*//Capteur Ultrason et Servomoteur
			hcsr04_state_machine();

			/*if(HCSR04_get_value(id_sensor, &distance) < DIST_MAX){
				SERVO_set_position(100); //Servo moteur a  100%
				HAL_Delay(2000);
			}
			else if(getCurrentPosition() != 100){
				SERVO_set_position(0); //Servo moteur a  0%
				HAL_Delay(2000);
			}*/


			SERVO_set_position(100); //Servo moteur a  100%
			HAL_Delay(2000);
			SERVO_set_position(0); //Servo moteur a  0%
			HAL_Delay(2000);

			//Fin de l'alarme
			if(button_center_press_event()){
				setAlarmSet(0);
				stopMusic(); //Stop la musique
				state = HOME;
			}

			break;


		default:
			break;
	}
}
